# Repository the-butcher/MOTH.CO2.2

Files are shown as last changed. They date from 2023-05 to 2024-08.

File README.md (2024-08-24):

# moth.CO2.2

This projects provides instructions for building a CO₂ sensor from off the shelve electronic parts combined with 3D printed housing parts.

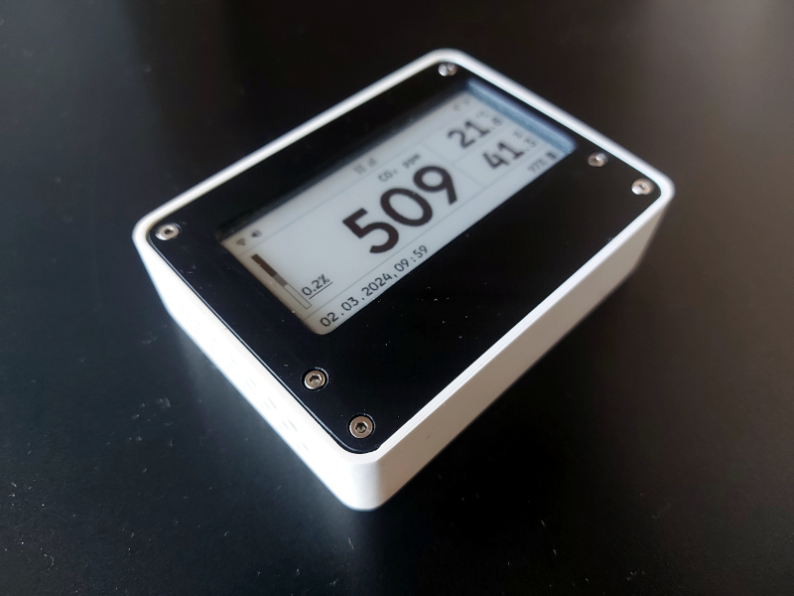
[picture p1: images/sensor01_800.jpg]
CO₂-Sensor fully assembled


- measures
  - CO₂
  - temperature
  - humidity
  - pressure
  - altitude
  - battery

- can last ~6 weeks on a single battery charge, when operated at low power settings, this is the longest battery life of a SCD41 based sensor operated at regular interval as far as i know

- uses the [Sensirion SCD-41](https://www.adafruit.com/product/5190) Sensor, a small and high performance photoacoustic NDIR CO₂ sensor

- offers various ways to access the data measured
  - on the device display in table or chart mode
  - through an integrated [wifi-rest-api](/moth_client/README.md#wifi-rest-api)
  - over the standardized [MQTT protocol](/moth_core/README.md#mqttjson)

- is configurable in many ways
  - thresholds for CO₂, temperature and humidity
  - temperature display in °C or °F
  - sensor timezone
  - temperature offset
  - CO₂ calibration
  - WiFi, [MQTT](https://de.wikipedia.org/wiki/MQTT)

- stores unlimited history of data due to integrated SD-card

- hosts a web-UI on it's internal web-server, usable from mobile and desktop devices

- optionally provides
  - dark/inverted mode
  - acoustic alert

<!-- ![chart mode](/images/sensor03_800.jpg?raw=true)

![WiFi connection](/images/sensor04_800.jpg?raw=true) -->

---

## The project is structured as follows:

### [Core (moth_core)](moth_core/README.md)

This project is built with [PlatformIO](https://platformio.org/). Please refer to the instructions provided on the PlatformIO website. PlatformIO makes development with the ESP32 microcontroller easier and faster compared to the Arduino IDE. If you have not switched yet i advise you to do so, it will save you time after a very short period of time.
The PlatformIO project, and configuration files can be found here.

### [Building instructions (moth_parts)](moth_parts/README.md)

Building instructions, drawings and printable files for the device.

### [Client (moth_client)](moth_client/README.md)

A react UI for data retrieval and administration of the device.

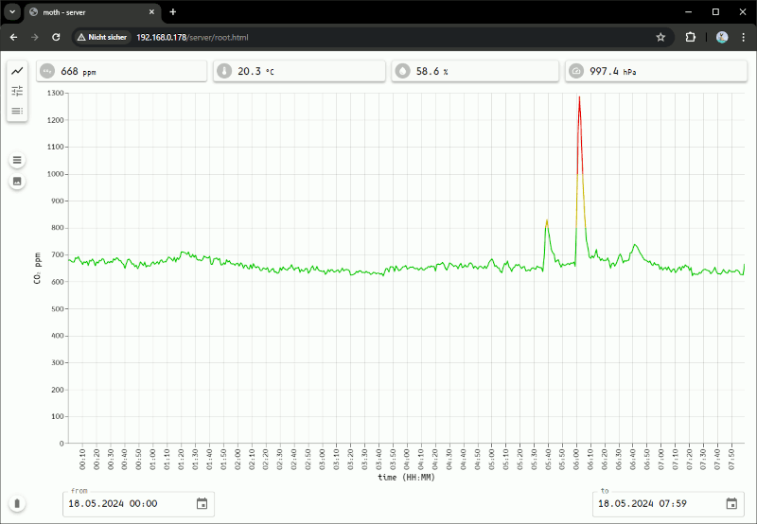
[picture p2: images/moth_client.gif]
web-app client


---

## Device functionality:

### Device usage

- #### Buttons

- #### Table mode

- #### Chart Mode

- #### CO₂ sound alert

- #### Wifi

- #### Dark mode

- #### Altimeter

### Data access

- #### On display

The device display supports multiple display modes, "table", "chart" and "calibration".

  - In table mode the latest CO₂, temperature and  humidity values are shown numerically.
  - In chart mode one of CO₂, temperature, humidity or pressure are shown in a simple chart. The chart can show 1h, 3h, 6h, 12h or 24h data ranges.
  - In calibration mode, the most recent history of values is shown together with simple statistics. The device can then be calibrated either to a configurable value via button press, or through the wifi-rest-api and value that can be specified by the user.

- #### Over the wifi-rest-api

  The device provides various possibilities to access current and historic data over the wifi-rest-api.

- #### MQTT

  It is possible to configure a mqtt connection and upload the mqtt brokers certificate if needed. The device will make connections in configurable intervals und publish it's measurements.
  The sensor can easily be integrated into HomeAssistant.

### Calibration

- #### On display (no wifi required)

The device display can be switched to calibration display mode, then put outside into fresh air. After 10 minutes the recent measurement history standard deviation can be checked and, if within plausible tolerance, the device can be calibrated to a reference value previously configured. See [moth_core/disp.json](/moth_core/README.md#dispjson) and [moth_client/client_config](/moth_client/README.md#client-config) for more details.

- #### Over the wifi-rest-api

The rest-api of the device provides the "co2cal" endpoint. Here it is possible to calibrate the device to any value above 400pmm. This enables calibration to value other than outside air, if known from i.e. other devices (see: [moth_client/wifi-rest-api](/moth_client/README.md#wifi-rest-api)) for more detail.

---

## License

Please be aware that all software in this project is licensed under the [MIT license](license.txt), while the drawings and 3d-printed parts are licensed under the [Attribution-NonCommercial-ShareAlike 4.0 International (CC BY-NC-SA 4.0)](https://creativecommons.org/licenses/by-nc-sa/4.0/) license.

https://github.com/the-butcher/MOTH.CO2.2/assets/84620977/23303f60-04a6-4f3b-a14d-cb0d6dc5e2be

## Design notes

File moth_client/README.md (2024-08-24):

## CLient

---

The client subproject is react-web-application, storable on the device's SD-card and consumable with any browser directly from the device.

The Client UI is split into 3 main pages:

---

- #### client-chart

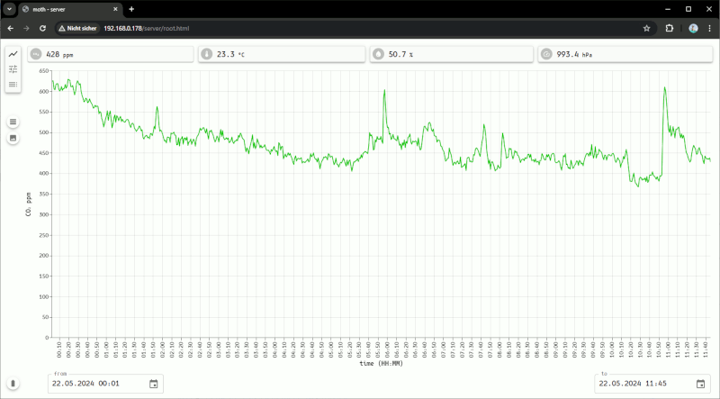
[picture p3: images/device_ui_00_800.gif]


It is possible to show recent and historic data:

- CO₂ (ppm)
- temperature (°C)
- humidity (%RH)
- barometric pressure (hPa)
- battery (%)

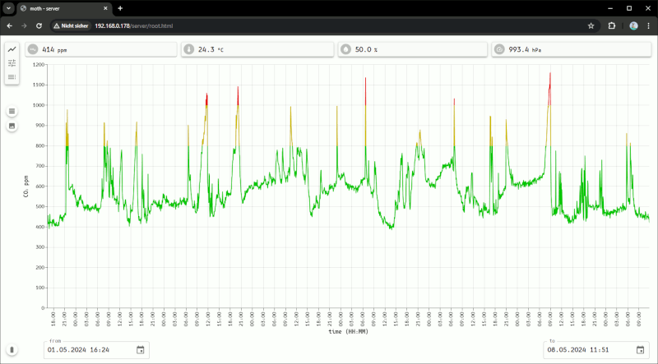
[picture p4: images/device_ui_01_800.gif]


Date/Time Pickers can be used to specify the range of data to be shown in the chart. Since the SD-card is large enough to store the entire lifetime of the sensor, so any date range from the life time of the sensor can be picked.

The displayed range of data can be exported to:

  - CSV
  - PNG

---

- #### client-config

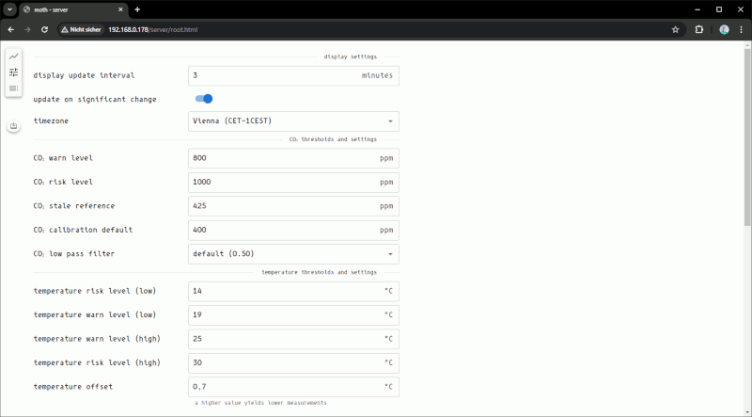
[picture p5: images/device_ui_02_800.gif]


This page offers a convenient way to configure the device through a reactive UI.

- #### client-api

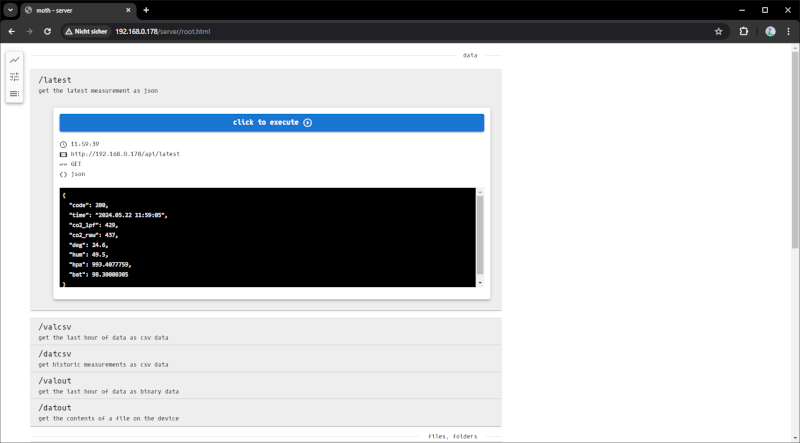
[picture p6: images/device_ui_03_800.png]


This is a helper page to descibe the device's api. This page can either be used as-is, or it can serve as the basis to understand the device api.

---

#### wifi-rest-api

A short list of the device's api:

|url|method|type|description|parameters|
|---|---|---|---|---|
|/api/latest|GET|json|get the latest measurement as JSON|none|
|/api/valcsv|GET|csv|get the last hour of measurements as CSV|none|
|/api/datcsv|GET|csv|get the contents of a data file as CSV|"file"<br>i.e. 2024/05/20230526.dat|
|/api/valcsv|GET|binary|get the last hour of measurements as binary data|none|
|/api/datout|GET|binary|get the contents of a file as binary data|"file"<br>i.e. 2024/05/20230526.dat|
|/api/dirout|GET|json|list the contents of a folder|"folder"<br>i.e. "2024", "2024/05/", "config"|
|/api/upload|POST|json|upload files to the device|"file"<br>i.e. "server/root.html"<br>"content"<br>multipart file content|
|/api/datdel|GET|json|delete files from the device|"file"<br>i.e. 2024/05/20240526.dat|
|/api/dirdel|GET|json|delete folders from the device|"folder"<br>i.e. "2024", "2024/05/"|
|/api/dspset|GET|json|change device display|"p"<br>0: display mode -> v:[0:2]<br>1: display theme -> v:[0:1]<br>2: table value-> v:[0:2]<br>3: chart value-> v:[0:5]|
|/api/status|GET|json|get details about device status|none|
|/api/netout|GET|json|get a list of networks visible to the device|none|
|/api/netoff|GET|json|disconnect the device|none|
|/api/co2cal|GET|json|calibrate the CO₂ sensor to a given reference value|"ref"<br>i.e. 420|
|/api/co2rst|GET|json|reset the CO₂ sensor to factory||
|/api/esprst|GET|json|reset the device||
|/api/update|POST|json|update device firmware|"content"<br>multipart file containing the new binary|

---

There are multiple ways connectivity to the device can be established:

- When no wifi-connection has been configured yet, the device will start in AP-mode, providing it's own network. You can connect you mobile phone or computer to that network and configure i.e. your home wifi. The AP connections password is "CO2@420PPM".
- When wifi-connections have been configured, the device will pick from the configured networks the one with the highest signal strength.

What has been working for me is configuring my home network and my mobile's wifi-hotspot. That way the sensor will connect to the home network most of the time, but there is a fallback to the hotspot of my phone when i'm away. When in a hotel i add the hotel network, so i can save data on the hotspot.

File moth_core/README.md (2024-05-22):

# Core

This folder contains the Arduino Sketch for the moth.CO2.2 sensor and a set of configuration files in [SD](SD) that need be copied to the SD card of the device.

The moth_core folder of the project is structured as follows:

---

Historic versions of the project (kept for reference):

- #### [moth_core_020](moth_core_020)
- #### [moth_core_021](moth_core_021)

Most recent PlatformIO project:

- #### **[moth_core_022](moth_core_022)**

---

Configuration files that define the behaviour of the device.

## [SD/config](SD/config/)

---

- ### [disp.json](SD/config/disp.json)

Configuration for everything related to displaying values.

documentation (please do not use the documented version on the device, but a clean json without the comments):

```
{
  "min": 3, <<< display update time in minutes
  "ssc": true, <<< allow shorter display update when a significant value change occured
  "alt": 153, <<< base altitude of the device
  "tzn": "CET-1CEST,M3.5.0,M10.5.0/3", <<< timezone
  "co2": {
    "wHi": 800, <<< co2 warn limit
    "rHi": 1000 <<< co2 risk limit
    "ref": 425, <<< co2 reference value for stale calculation
    "cal": 400, <<< co2 reference value for fresh air calibration
    "lpa": 0.5  <<< low pass filter alpha, low value yields stronger filtering
  },
  "deg": {
    "rLo": 14, <<< lower temperature (celsius) risk limit
    "wLo": 19, <<< lower temperature (celsius) warn limit
    "wHi": 25, <<< upper temperature (celsius) warn limit
    "rHi": 30, <<< upper temperature (celsius) risk limit
    "off": 1.5, <<< temperature offset of the scd41 sensor
    "c2f": false <<< temperature display in fahrenheit?
  },
  "hum": {
    "rLo": 25, <<< lower humidity (% RH) risk limit
    "wLo": 30, <<< lower humidity (% RH) warn limit
    "wHi": 60, <<< upper humidity (% RH) warn limit
    "rHi": 65  <<< upper humidity (% RH) risk limit
  },
  "bme": {
    "alt": 153, <<< base altitude of the sensor
    "lpa": 0.25 <<< low pass filter alpha, low value yields stronger filtering
  }
}
```
General timezone documentation can be found at:
[timezones](https://github.com/nayarsystems/posix_tz_db/blob/master/zones.csv)

Measurements are stored with local times.

Timezones that have been tested to work are (but other will work too):

|code|where|
|---|---|
|CET-1CEST,M3.5.0,M10.5.0/3|Vienna|
|GMT0BST,M3.5.0/1,M10.5.0|London|
|AST4ADT,M3.2.0,M11.1.0|Atlantic|
|EST5EDT,M3.2.0,M11.1.0|New York|
|CST6CDT,M3.2.0,M11.1.0|Chicago|
|MST7MDT,M3.2.0,M11.1.0|Denver|
|PST8PDT,M3.2.0,M11.1.0|Los Angeles|

example:

```
{
  "min": 3,
  "ssc": true,
  "tzn": "CET-1CEST,M3.5.0,M10.5.0/3",
  "co2": {
    "wHi": 800,
    "rHi": 1000,
    "ref": 425,
    "cal": 400,
    "lpa": 0.5
  },
  "deg": {
    "rLo": 14,
    "wLo": 19,
    "wHi": 25,
    "rHi": 30,
    "off": 1.5,
    "c2f": false
  },
  "hum": {
    "rLo": 25,
    "wLo": 30,
    "wHi": 60,
    "rHi": 65
  },
  "bme": {
    "alt": 153,
    "lpa": 0.25
  }
}
```

- ### [mqtt.json](SD/config/mqtt.json)

Configuration for [MQTT](https://de.wikipedia.org/wiki/MQTT).

documentation (please do not use the documented version on the device, but a clean json without the comments):

```
{
  "use": true, <<< use mqtt?
  "srv": "192.168.0.123", <<< mqtt broker host (required)
  "prt": 8883, <<< mqtt broker port (required)
  "usr": "hannes", <<< mqtt user (optional)
  "pwd": "n7NZ+SfvP68wzUgh3t4acw==", <<< mqtt password (optional)
  "cli": "moth_2", <<< the mqtt client-id that the device will use
  "min": 5 <<< publish interval in minutes
}
```

example (protected, if a certificate is present at "/config/ca.crt" secure):

```
{
  "use": true,
  "srv": "192.168.0.115",
  "prt": 8883,
  "usr": "hannes",
  "pwd": "fleischer",
  "cli": "moth__66",
  "min": 5
}
```

example (unprotected server, if the server does not require a secure connection, the certificate file "/config/ca.crt" should not exist):

```
{
  "use": true,
  "srv": "192.168.0.115",
  "prt": 1883,
  "cli": "moth__66",
  "min": 5
}
```

example (mqtt inactive):

```
{
  "use": false
}
```

for all above configurations, if there is a certificate present at "/config/ca.crt", a secure wifi-connection will be created using that certificate.

- ### [wifi.json](SD/config/wifi.json)

Configuration for the WiFi connection of the decive.

documentation (please do not use the documented version on the device, but a clean json without the comments):

```
{
  "min": 5, <<< wifi timeout in minutes, when not connected to power, wifi will auto turn off after that time
  "ntw": [ <<< an array of network connections
    {
      "key": "your-wifi-ssid", <<< the ssid of your network
      "pwd": "your-wifi-password" <<< the password of your network
    }
  ]
}
```

example:

```
{
  "min": 5,
  "ntw": [
    {
      "key": "your-wifi-ssid",
      "pwd": "your-wifi-password"
    }
  ]
}
```

example (unprotected network):

```
{
  "min": 5,
  "ntw": [
    {
      "key": "your-wifi-ssid",
      "pwd": ""
    }
  ]
}
```

## [SD/server](SD/server/)

The device provides webserver accessible through WiFi. The files in this folder provide a web-application that can be used to administer the device

The files for the webserver are built from the [moth_client_p22](../moth_client_p22/) subproject.

---

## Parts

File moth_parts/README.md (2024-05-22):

# <a name="moth_parts">Parts and Assembly</a>
Building the sensor is split into two main parts. Electric assembly and housing.

---
### [Electric parts](electricparts.md)

List of parts that need to be bought.

---
### [Electric Assembly](electricassembly.md)

Assembly instructions for the electric parts. Simple soldering required.

---
### [Printed parts](printedparts.md)

List of printable parts and some postprocessing hints.

---
### [Device Assembly](deviceassembly.md)

Assembly of the device from electric and printed parts.

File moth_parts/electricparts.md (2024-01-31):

# Electric parts

Parts used in the prototype build:

- <a href="#microcontroller">Adafruit ESP32-S2 Feather with BME280</a>
- <a href="#co2sensor">Adafruit SCD-41 - True CO2 Temperature and Humidity Sensor - STEMMA QT / Qwiic</a>
- <a href="#rtc">Adafruit PCF8523 Real Time Clock Breakout Board - STEMMA QT / Qwiic</a>
- <a href="#cable">STEMMA QT / Qwiic JST SH 4-Pin Cable - 50mm Long x 2</a>
- <a href="#display">Adafruit 2.9" Grayscale eInk / ePaper Display FeatherWing - 4 Level Grayscale</a>
- <a href="#battery">3,7 V 3000mAh 18650 Lithium Li-Ion Battery Pack</a>
- <a href="#buzzer">Buzzer</a>
- <a href="#screws">M2 hardware</a>
- <a href="#inserts">threaded inserts M2 x 4mm</a>
- <a href="#acrylic">acrylic glas 1mm, ~ 78mm x ~36mm</a>

The list contains references to where i got my parts from, if you get alterntive parts please consider any differences that may make for the 3D-printed parts. For example, if you get different threaded nuts, you may have to adapt the openings provided to those inserts.

---

<a href="https://www.adafruit.com/product/5303" name="microcontroller">Adafruit ESP32-S2 Feather with BME280</a> The microcontroller. Not an S3, but it has an BME-280 Sensor onboard, thus saving an extra part to be fit into the housing. The processors power is far beyond necessary and the pressure sensor delivers extra precision to the CO₂ sensor.

Adafruit ESP32-S2 Feather with BME280

---

<a href="https://www.adafruit.com/product/5190" name="co2sensor">Adafruit SCD-41 - True CO2 Temperature and Humidity Sensor - STEMMA QT / Qwiic</a> The actual CO₂ sensor. Easy to connect due STEMMA QT connection with the microcontroller.

Adafruit SCD-41 - True CO2 Temperature and Humidity Sensor - STEMMA QT / Qwiic

---

<a href="https://www.adafruit.com/product/5189" name="rtc">Adafruit PCF8523 Real Time Clock Breakout Board - STEMMA QT / Qwiic</a> Battery-backed real time clock (RTC)

Adafruit PCF8523 Real Time Clock Breakout Board - STEMMA QT / Qwiic

---

<a href="https://www.adafruit.com/product/4399" name="cable">STEMMA QT / Qwiic JST SH 4-Pin Cable - 50mm Long</a> Cables connecting microcontroller, RTC and CO₂ sensor. 2 cables are needed.

STEMMA QT / Qwiic JST SH 4-Pin Cable - 50mm Long

---

<a href="https://www.adafruit.com/product/4777" name="display">Adafruit 2.9" Grayscale eInk / ePaper Display FeatherWing - 4 Level Grayscale</a> Grayscale e-ink display

Adafruit 2.9 Grayscale eInk / ePaper Display FeatherWing - 4 Level Grayscale

---

<a href="https://batteryzone.de/products/3-7-v-3000mah-18650-lithium-li-ion-batterien-pack-wiederaufladbare-mit-xh-2-54mm-2pin-stecker-fur-rc-boot-diy-power-bank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" name="battery">3,7 V 3000mAh 18650 Lithium Li-Ion Battery Pack</a>  18650 Battery Pack with PH2.0 plug.

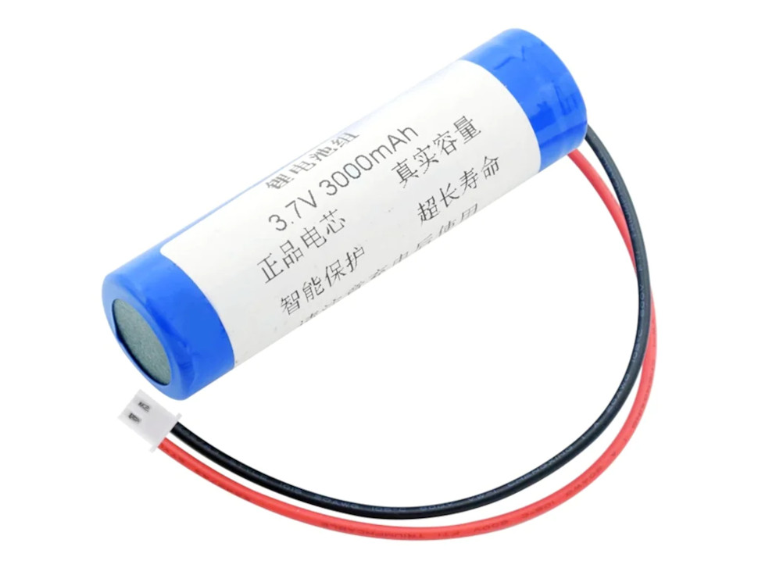
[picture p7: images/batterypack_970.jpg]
3,7 V 3000mAh 18650 Lithium Li-Ion Battery Pack


---

<a href="https://www.mouser.at/ProductDetail/TDK/PS1240P02BT?qs=d7g9p1yFhWaZXSY9MjKMkw%3D%3D" name="buzzer">Buzzer</a>

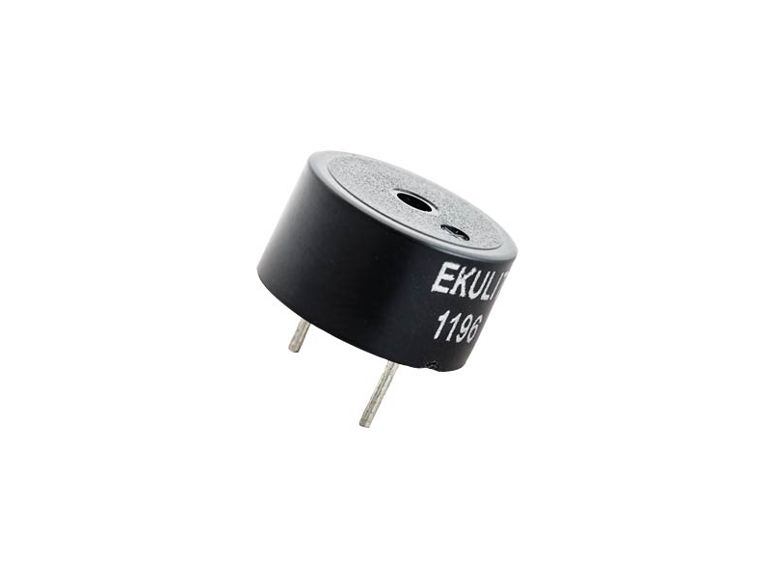
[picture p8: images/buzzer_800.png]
Buzzer


---

- <a name="screws">M2 hardware:</a>

  - 8 screws M2 x 5mm
  - 4 screws M2 x 8mm
  - 8 nuts M2

---

- 4 <a href="https://www.reichelt.at/at/de/3d-druck-gewindeeinsaetze-m2x4-70-stueck-rx-m2x4-p332211.html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" name="inserts">threaded inserts M2 x 4mm</a>

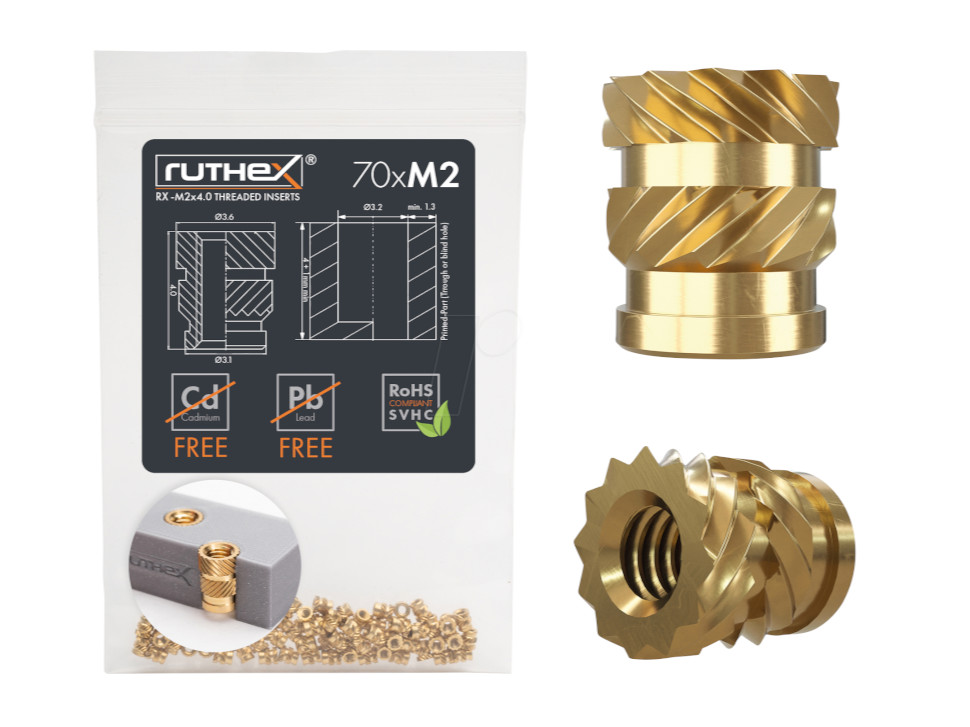
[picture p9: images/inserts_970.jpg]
threaded inserts M2 x 4mm


---

- <a name="acrylic">acrylic glas 1mm, ~ 78mm x ~36mm</a>

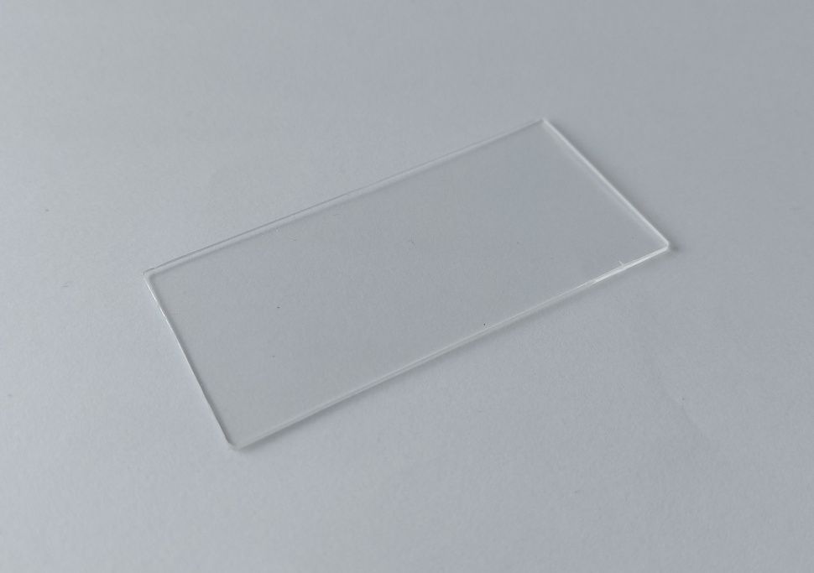
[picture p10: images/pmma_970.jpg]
acrylic glas 1mm


---

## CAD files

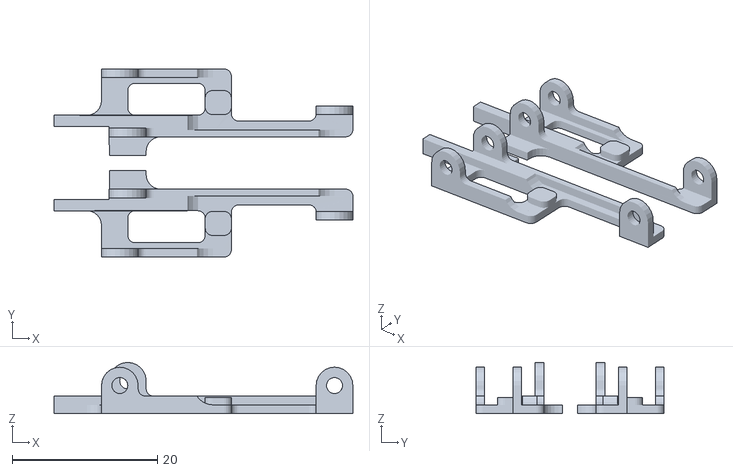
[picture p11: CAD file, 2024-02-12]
moth_parts/supports2.stl
41.1 x 25.9 x 7.03

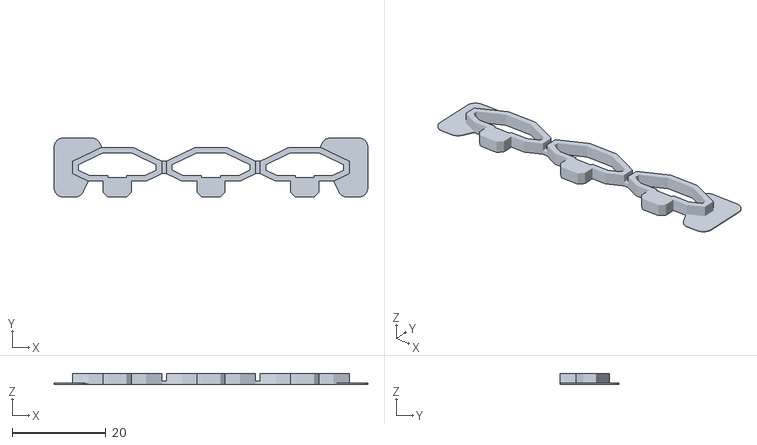
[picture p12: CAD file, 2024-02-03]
moth_parts/buttons_tpu.stl
67.0 x 12.6 x 2.42

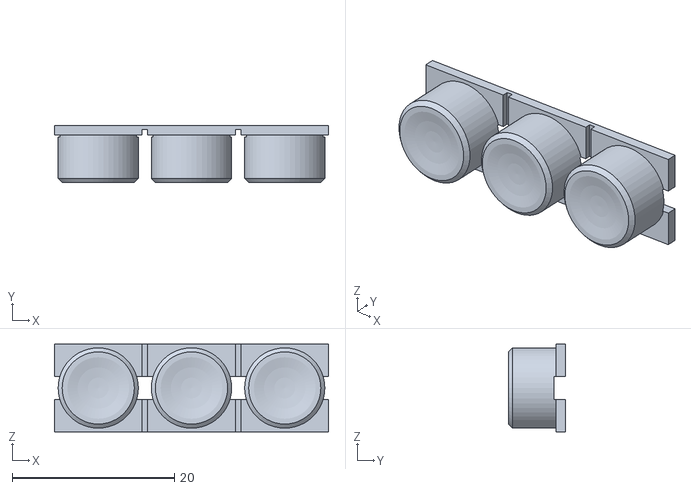
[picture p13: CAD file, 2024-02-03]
moth_parts/buttons.stl
33.8 x 7.05 x 10.8

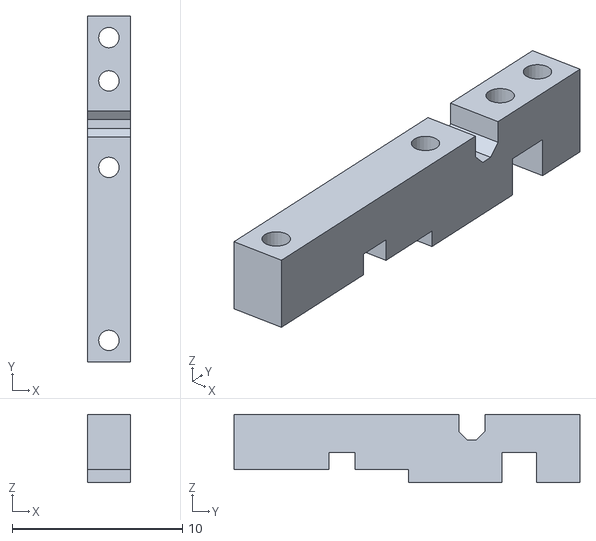
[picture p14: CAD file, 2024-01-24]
moth_parts/boostbuzz.stl
2.52 x 20.3 x 4.00

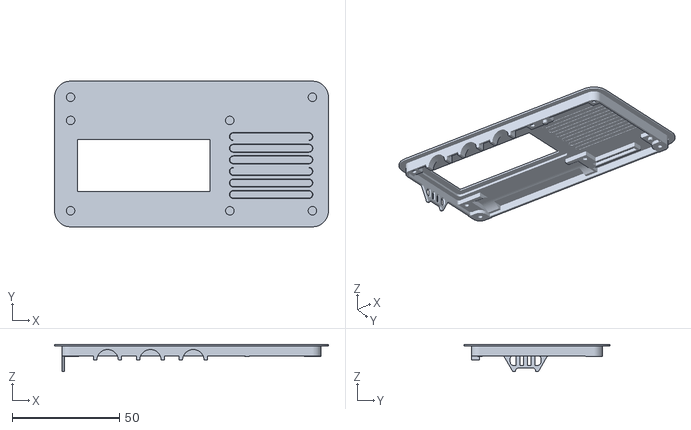
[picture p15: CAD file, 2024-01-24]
moth_parts/housing_upper_pms.stl
127.9 x 68.0 x 12.8

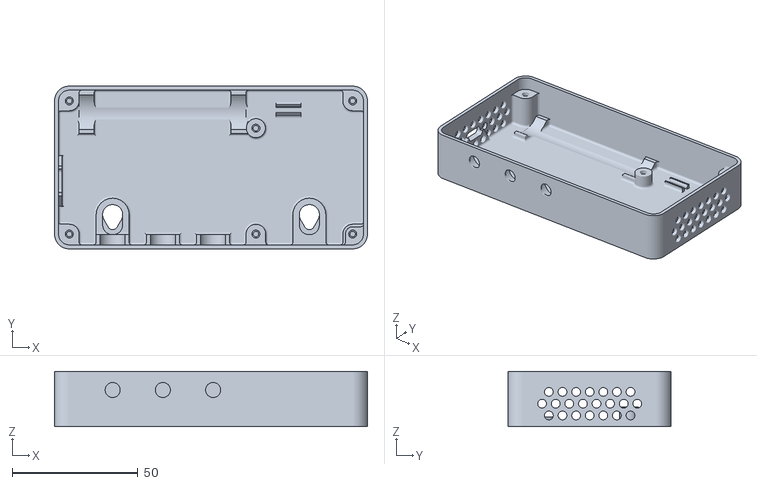
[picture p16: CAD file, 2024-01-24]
moth_parts/housing_lower_pms.stl
124.7 x 64.8 x 22.0

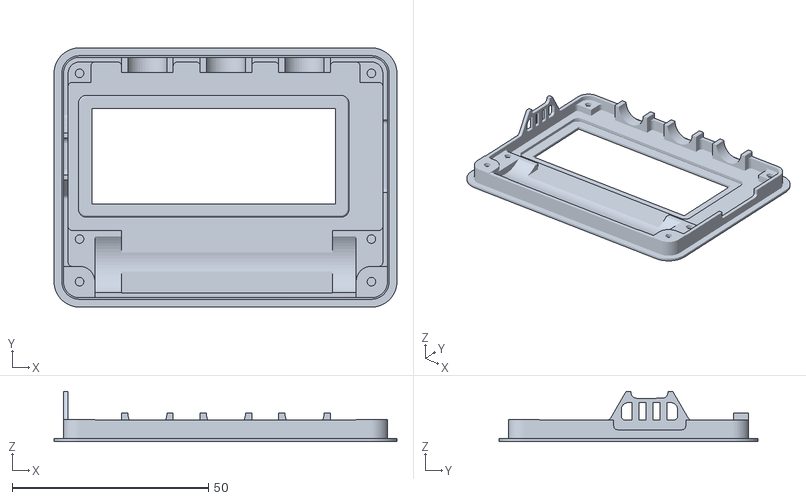
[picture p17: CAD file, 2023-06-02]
moth_parts/housing_upper_b.stl
87.3 x 66.0 x 12.8

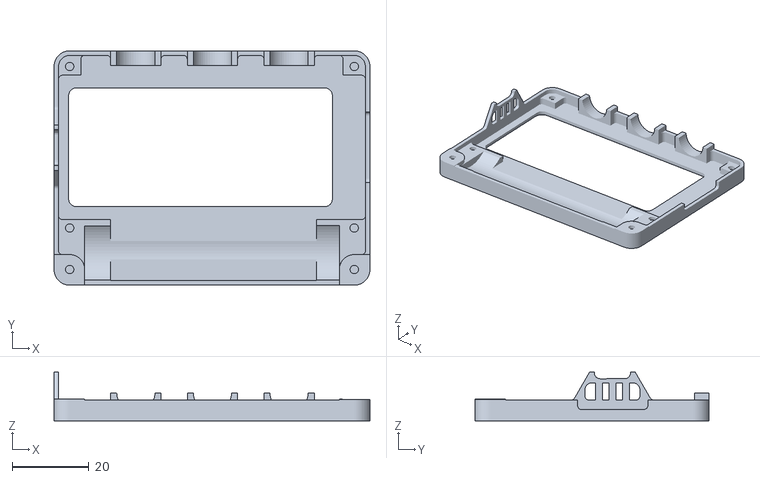
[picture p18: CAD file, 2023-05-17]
moth_parts/housing_upper.stl
82.5 x 61.2 x 12.8

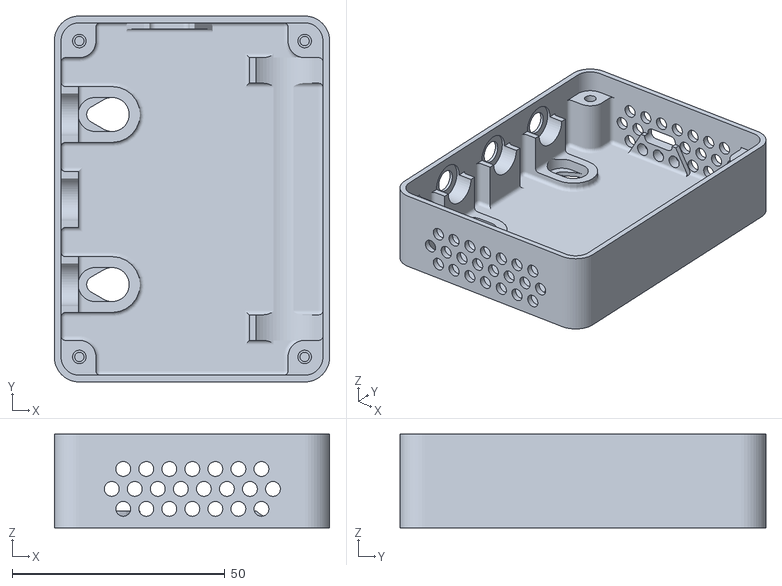
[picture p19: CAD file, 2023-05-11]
moth_parts/housing_lower_s.stl
64.8 x 86.1 x 22.0

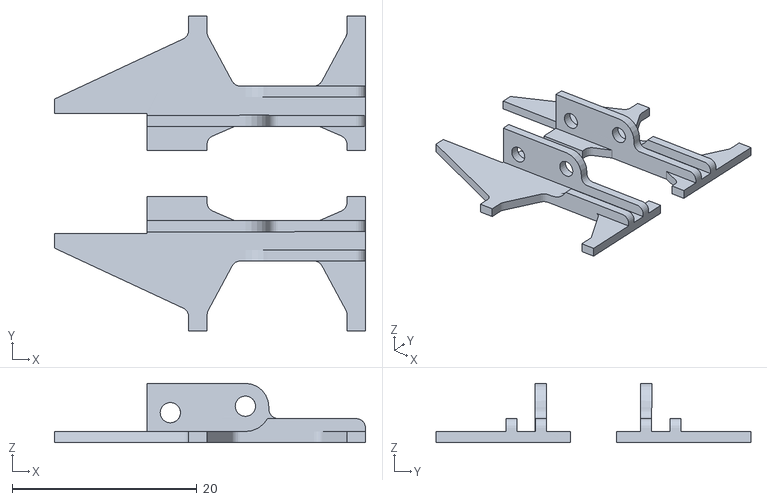
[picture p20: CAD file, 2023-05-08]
moth_parts/supports.stl
33.7 x 34.1 x 6.42

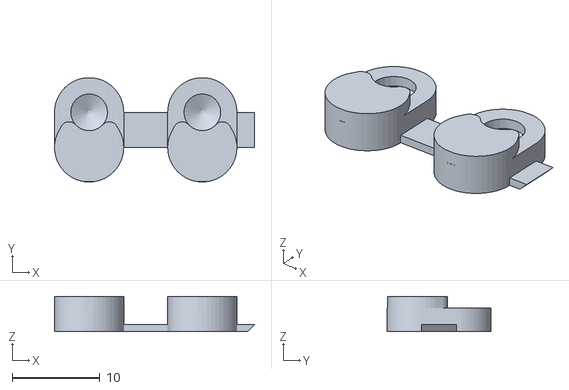
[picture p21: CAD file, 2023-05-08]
moth_parts/mountplugs.stl
22.8 x 11.9 x 4.02

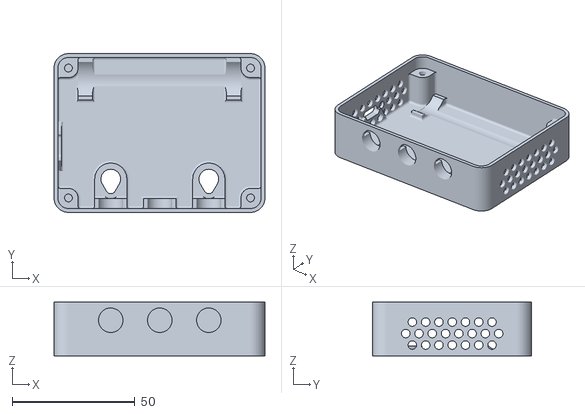
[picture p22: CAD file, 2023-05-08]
moth_parts/housing_lower.stl
86.1 x 64.8 x 22.0

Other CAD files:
moth_parts/boostbuzz.skp
moth_parts/buttons.skp
moth_parts/buttons_tpu.skp
moth_parts/housing_lower.skp
moth_parts/housing_lower_pms.skp
moth_parts/housing_upper.skp
moth_parts/housing_upper_pms.skp
moth_parts/mountplugs.skp
moth_parts/supports.skp
moth_parts/supports2.skp

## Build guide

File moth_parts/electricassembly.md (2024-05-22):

# Electric Assembly

Lay the display flat on a soft surface (i.e. a piece of soft cloth). On the backside of the display solder a connection from the pad corresponding to the A4 pin to the pad labelled with "busy".

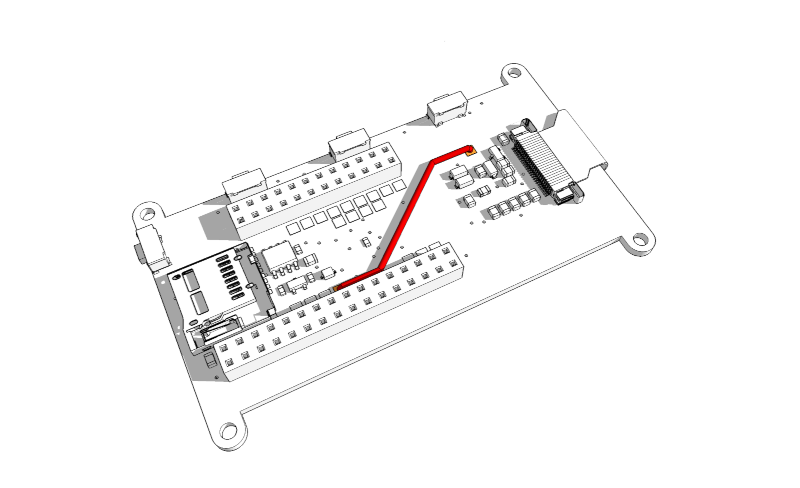
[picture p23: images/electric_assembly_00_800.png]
connect busy


---

Place the microcontroller directly over the the display. Stick short pins (should portrude ~1mm out when fully inserted) through each microcontroller pinhole into the respective display pinholes. Do NOT use a pin header strip, the microcontroller must sit directly on the display.

- Do NOT add a pin to the RST pinhole. This pin will be bridged to from the A0 pin to allow for display only reset. Adding the possibility to reset the display during runtime will save power between display updates. There is also an issue with gray speckles showing on the grayscale eInk display while powered, being able to hibernate the display and reset it later takes care of this issue.
- Do NOT add a pin to the D13 pinhole. The D13 pin on the Adafruit Feather ESP32-S2 is tied to the D13 pin, but this pin is also being used by the C-Button of the eInk display. Therefore the red led of the ESP will always be on when using INPUT_PULLUP for this pin. This consumes power and shortens battery life. This pin will be bridged to from the D6 pin. That way the C-Button is effecticely rerouted to D6 and the red led will no be on, thus saving power.

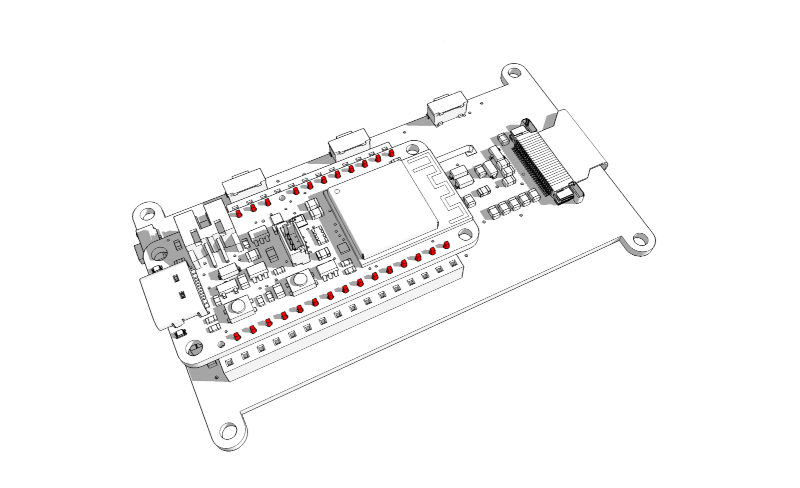
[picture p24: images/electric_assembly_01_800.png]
pins


---

Solder all pins (not RST, not D13) to the microcontroller. After soldering you can separate microcontroller and display. You should now have the microcontroller with short pins soldered to it.

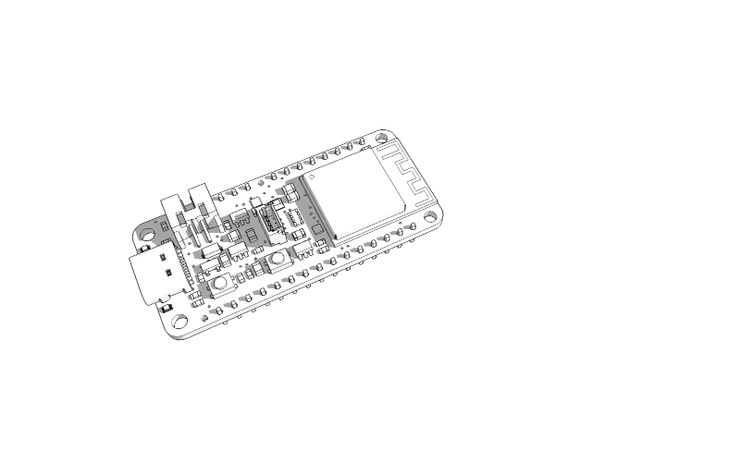
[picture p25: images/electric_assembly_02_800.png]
s2 with pins


---

3d-print [STL "supports2"](supports2.stl), clean printed parts with a file or sandpaper, cleanup holes with a 2mm drill if required. Use 6 M2 x 5mm screws and 6 M2 nuts to connect the feather esp32-s2 microcontroller and the scd-41 sensor. Try not to touch the CO₂ sensors central part to avoid contamination. Connect microcontroller, RTC and scd-41 sensor with the Stemma QT cables (not pictured).

I removed the yellow leds from both RTC and scd-41 with a scalpel. This will significantly prolong battery lifetime, but you must be aware that it will void the warranty for the respective parts.

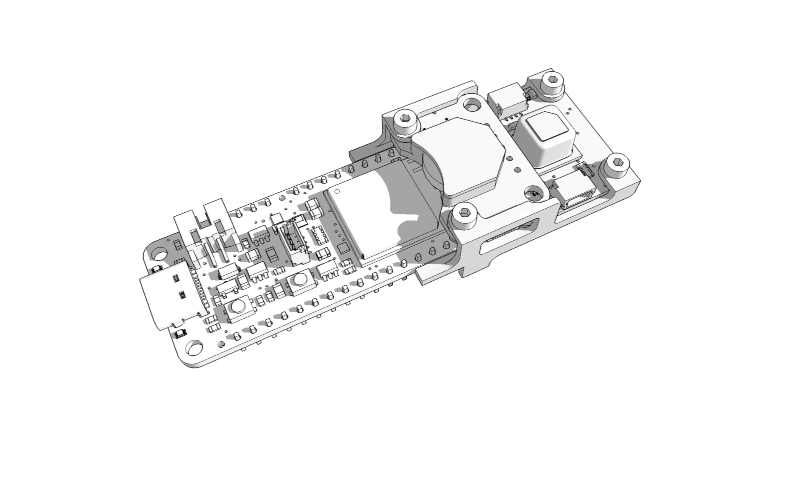
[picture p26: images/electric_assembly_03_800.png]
s2 scd41 and supports


---

Carefully reattach to display to get a unit of display, microcontroller, RTC and CO₂ sensor.

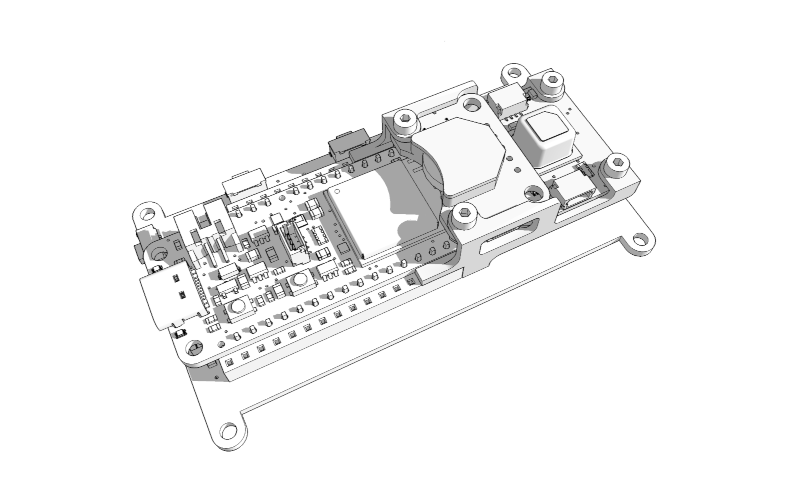
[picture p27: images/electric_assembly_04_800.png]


---

- Connect the pinhole corresponding to the microcontrollers A0 pin to the display RST pinhole. Normally the display would have been hardwirded to be microcontrollers reset button, but we need to be able to reset the display at runtime and this gives the possiblity to do so.
- Connect the pinhole corresponding to the microcontrollers D6 pin to the pinhole corresponding to the microcontrollers A13 pin. This allows for operation of the C-Button on the display without having the microcontrollers red led on.
- Connect the SQW pin of the RTC to the microcontrollers A5 pin. I used thin pliers to bend the connection wire so it would follow the contour of the support parts.

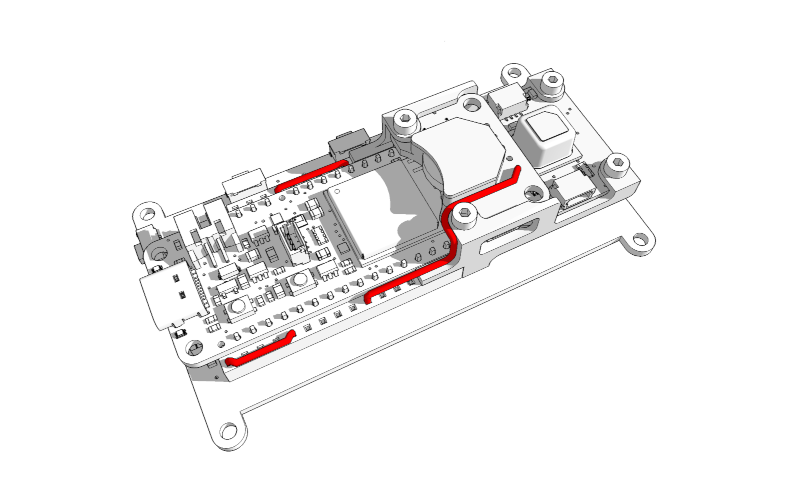
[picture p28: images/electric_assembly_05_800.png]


---

Attach the Buzzer so its pins go into GND and A1.

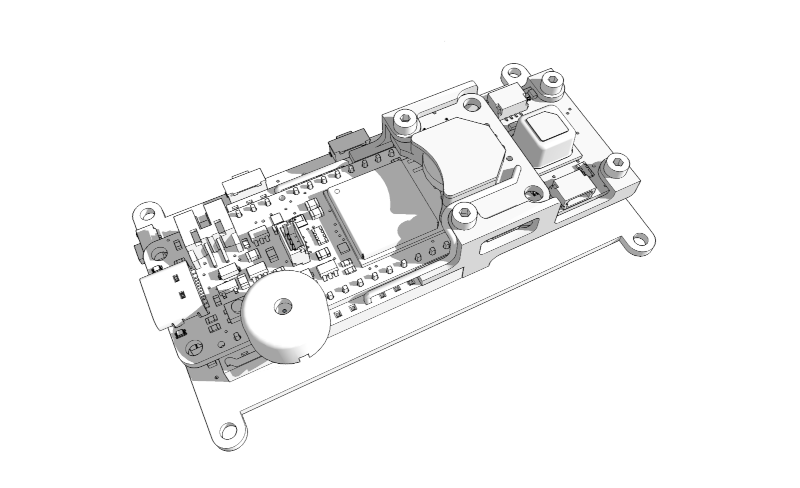
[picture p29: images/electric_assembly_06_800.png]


---

The Electric Assembly is now ready to be configured and to have a sketch uploaded. Please refer to [Core](../moth_core/README.md) for further instructions.

---

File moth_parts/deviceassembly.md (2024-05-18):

# Device Assembly

After having built the [Electric Assembly](electricassembly.md) and having printed and finished all [Printed parts](printedparts.md) all parts can be assembled to the full device.

---

User your soldering iron to press the threaded inserts into the lower housing, then insert the mountplugs into the lower housing if needed.

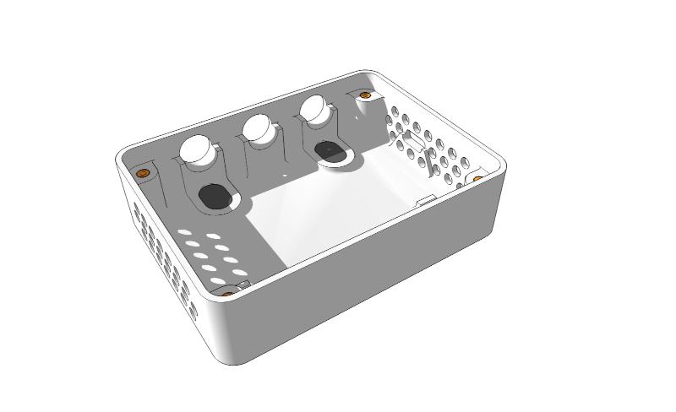
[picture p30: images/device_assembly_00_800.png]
lower housing


---

Cut a rectangle of acrylic glass to fit the upper housing.

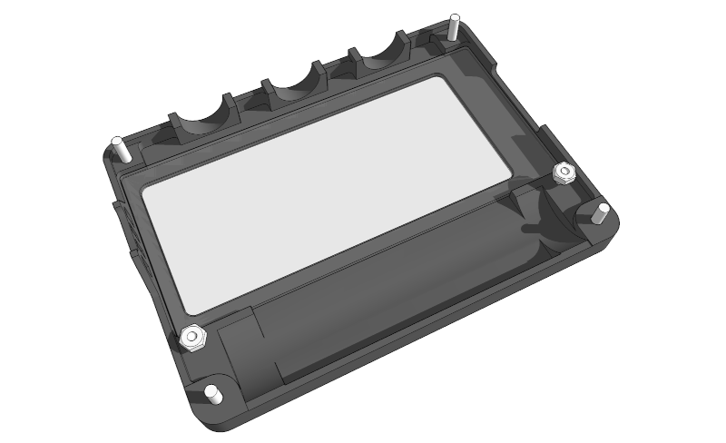
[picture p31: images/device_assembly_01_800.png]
acrylic glas 1mm


---

Place the [Electric Assembly](electricassembly.md) on top of the acrylic glass onto the upper housing and use 2 M2 x 5 screws and 2 M2 nuts to attach.

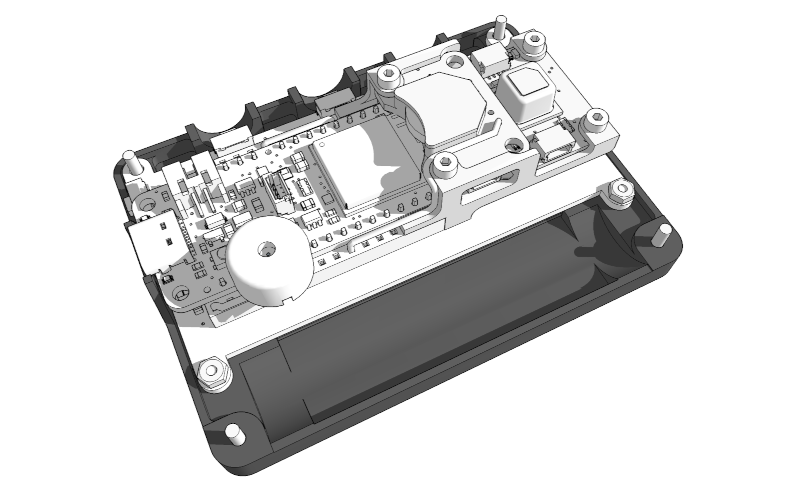
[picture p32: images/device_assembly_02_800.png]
electric assembly mount


---

Add the battery and find a place to lead the cable to the battery plug on the microcontroller. Double- and triplecheck polarity of the battery before plugging it into the microcontroller. I added 2 little drops of glue under the battery to ease handling afterwards.
I had to file a little edge off the buzzer to make battery and buzzer fit nicely.

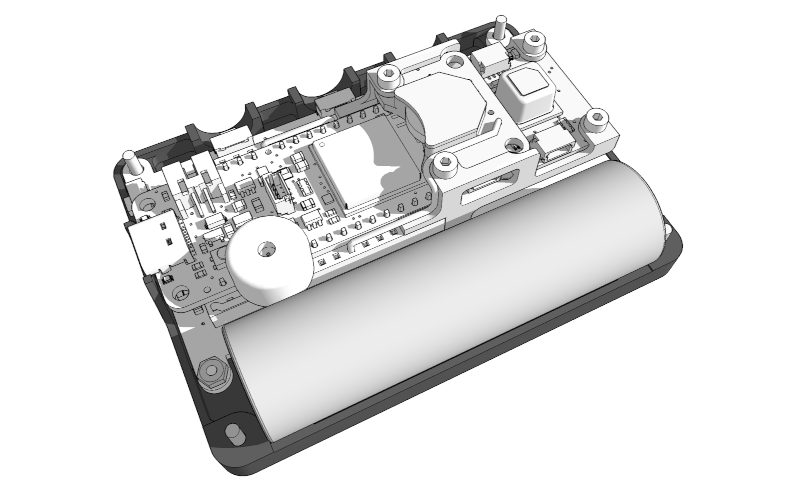
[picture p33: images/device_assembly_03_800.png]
battery


---

Seat the assembled buttons into the assembly and be sure each button can operate freely.

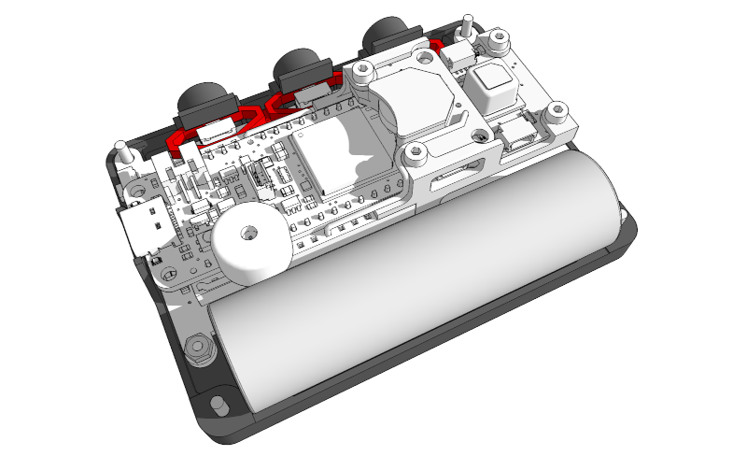
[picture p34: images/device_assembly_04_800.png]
buttons in lower housing


---

Place the lower housing upright so it can accept the rest of the assembly.

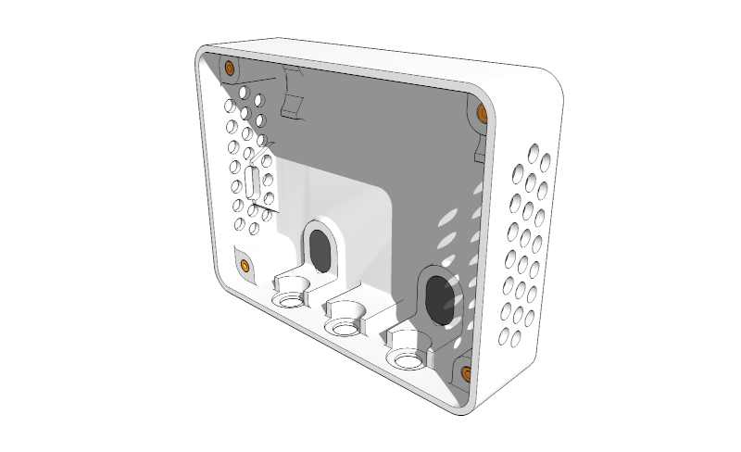
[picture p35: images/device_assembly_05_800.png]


---

Insert the assembly, buttons first, be sure all cables go in smoothly and dont block one the threads that connect lower and upper housing.
Once inserted add 4 M2 x 8mm screws for final attachment.

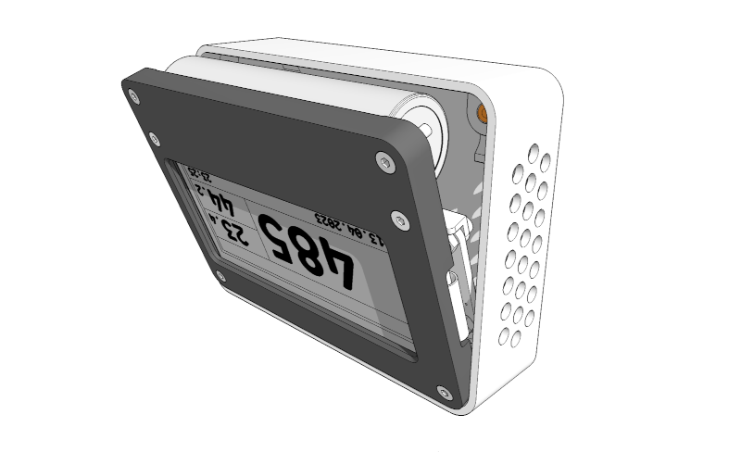
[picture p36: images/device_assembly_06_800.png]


---

Fully assembled.

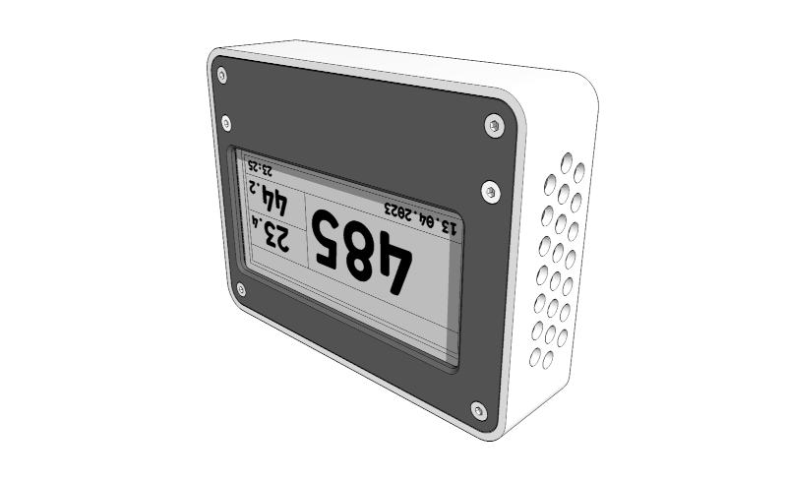
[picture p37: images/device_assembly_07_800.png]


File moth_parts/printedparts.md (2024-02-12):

# PRINTED parts

### [Lower Housing](housing_lower.stl)

This is the part taking the longest to print and also the one requiring most finishing.

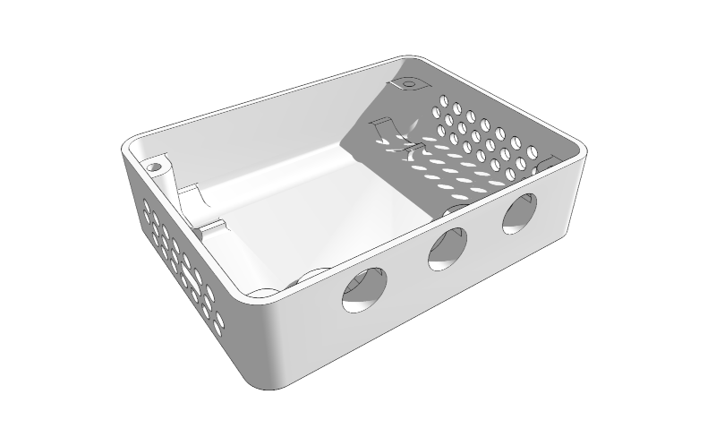
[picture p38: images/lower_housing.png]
lower housing


You can leave this part as it is and it should still work, but the device will look much better if you sand the layered surfaces to a smooth finish. I used 180 grain sandpaper on the surfaces marked red, then worked my way up to 320 grain, then 400 and 600.

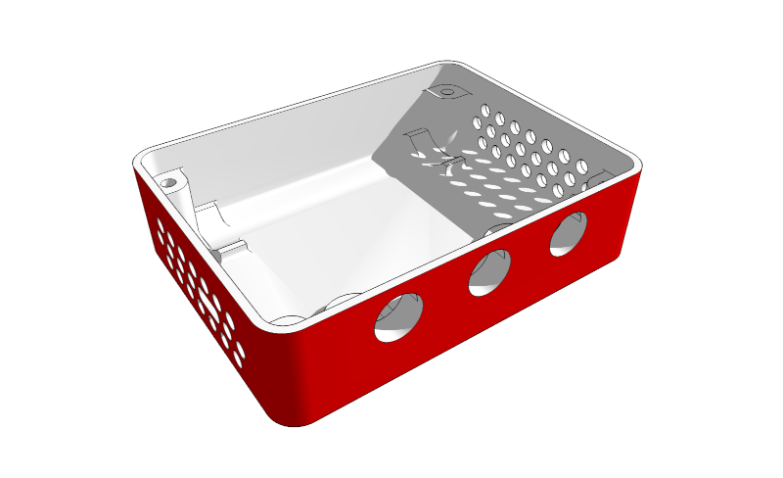
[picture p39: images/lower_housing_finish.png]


Next, i cleaned up the button openings for smooth button operation. Last step was opening all venting holes with a 4mm drill, this gives crisp edged on the surface and removes any artifact from printing overhang.

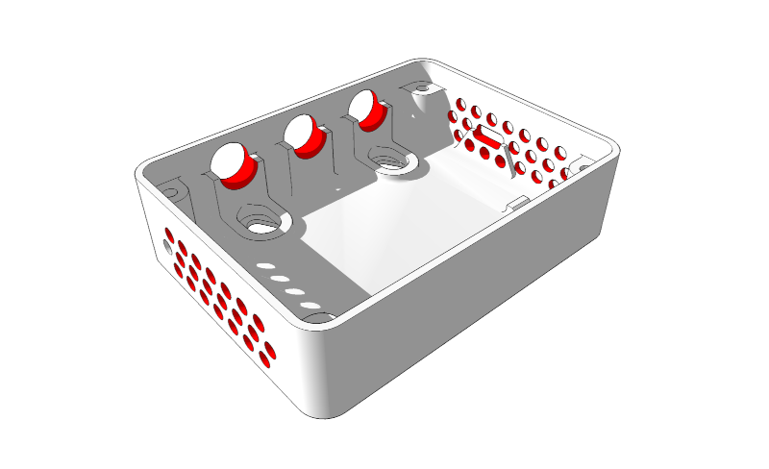
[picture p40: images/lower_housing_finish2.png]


---

### [Upper Housing](housing_upper.stl)

The upper housing takes less time to print and does not require any substantial finishing.

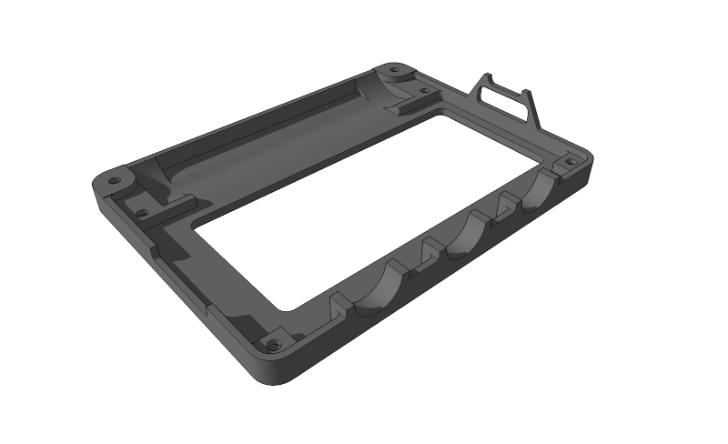
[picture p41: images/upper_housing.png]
upper housing


Again, you should be able to use the part as it is, but it will look better when you file/sand the display opening. You have to open the screwholes with a 2mm drill.

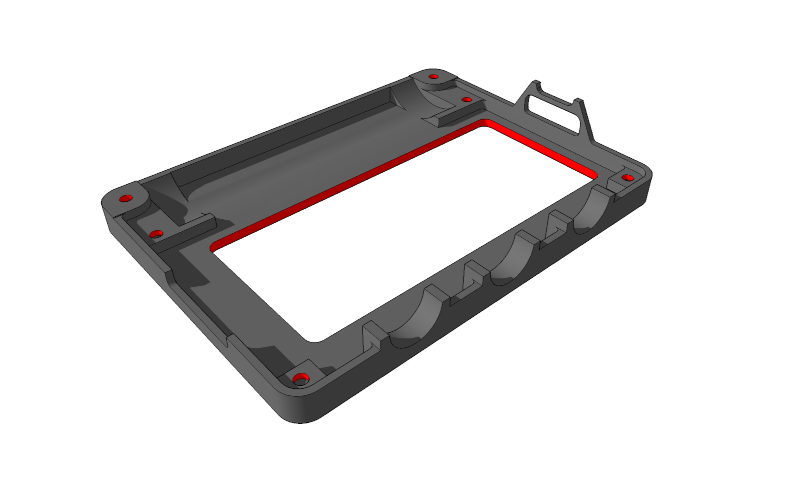
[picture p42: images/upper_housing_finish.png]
upper housing


#### [Upper Housing with raft](housing_upper_b.stl)

For unknown reasons, i had problems with warping on the upper housing part. To fix these issues, there is another version with thick rafts around the part borders.
---

### [Supports](supports2.stl)

The supports serve to connect microcontroller, RTC and the CO₂ sensor and also act as flexible support for the CO₂ sensor to reduce mechanical load should the device be dropped.

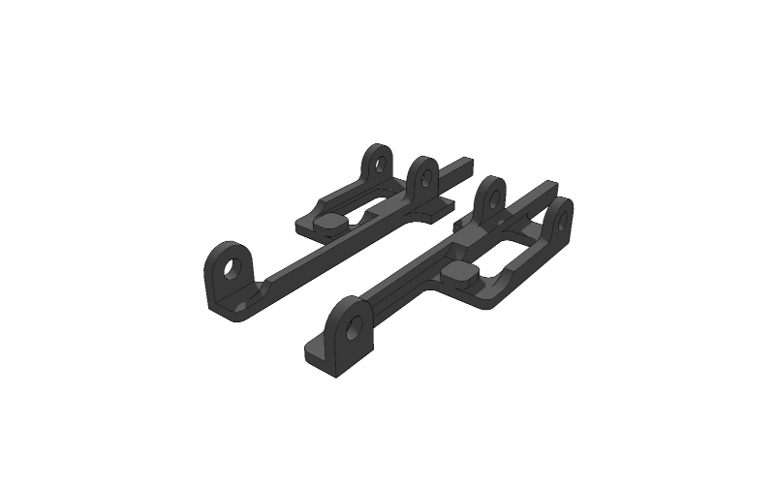
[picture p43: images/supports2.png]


---

### [Buttons](buttons.stl) and [Buttons springs](buttons_tpu.stl)

The buttons can later be used to toggle wifi, display and acoustic feedback.

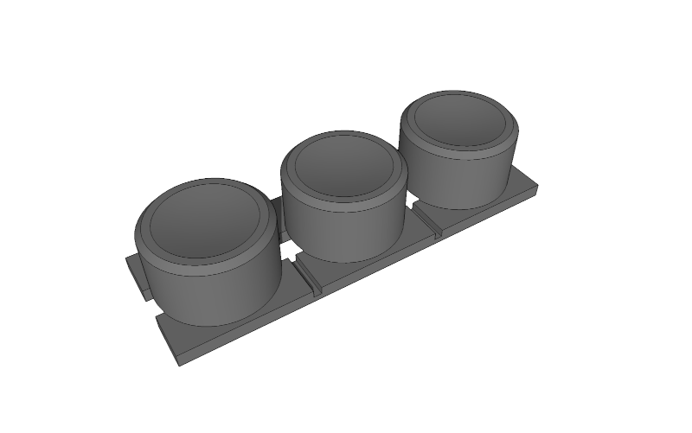
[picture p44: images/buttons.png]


Separate the buttons and clean with sandpaper.

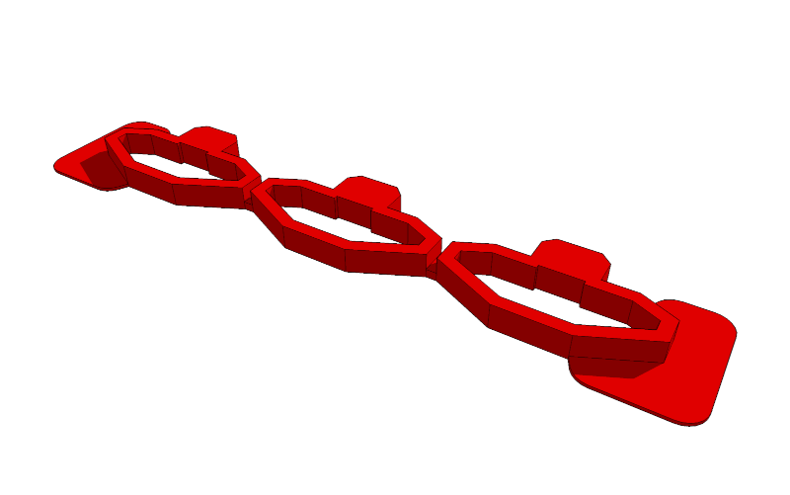
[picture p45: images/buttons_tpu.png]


This part needs to be printed with TPU. It adds flexible action to the buttons and also maintains some pressure on the button so there will be no loose sound when moving the device.
Once printed, remove the rafts with a sharp knive and clean up very precice for later fit.

---

### [Mountplugs](mountplugs.stl)

These little parts go into the wall mount openings of the lower housing. When inserted as printed, the device can not be wall mounted. When drilling through the plugs with a 4mm drill, but leavong the plug in the lower housing, the device can be mounted fixed which provides some degree of theft protection. When omitted altogether the device can be taken on or off the wall.

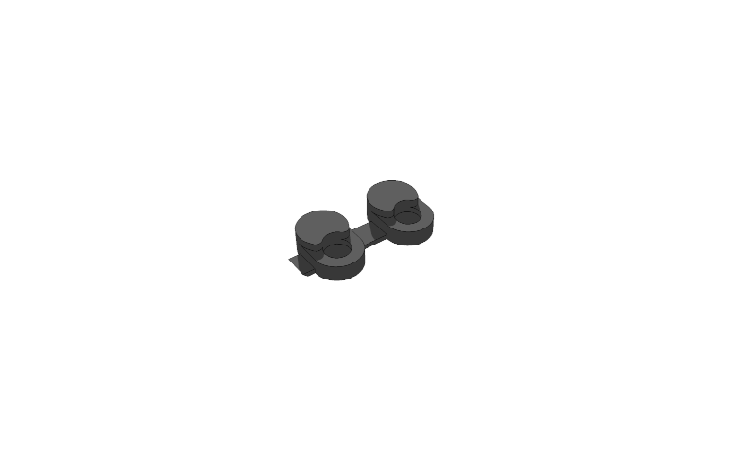
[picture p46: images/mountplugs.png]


---

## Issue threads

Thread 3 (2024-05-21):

do not allow device calibration when the variance of the previous measurements is too large

the-butcher, 2024-05-21:
The device allows calibration, even when the previous values are very high or have a high variation.

There should be limits both value-range and variance wise. If these thresholds are exceeded the calibrate button should not show an icon and should not be functional.

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

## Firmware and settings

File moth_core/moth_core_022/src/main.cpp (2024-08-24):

#include <Arduino.h>
#include <Wire.h>
#include <driver/rtc_io.h>
#include <esp_wifi.h>

#include "buttons/ButtonAction.h"
#include "modules/ModuleCard.h"
#include "modules/ModuleDisp.h"
#include "modules/ModuleMqtt.h"
#include "modules/ModuleSignal.h"
#include "modules/ModuleWifi.h"
#include "sensors/SensorBme280.h"
#include "sensors/SensorEnergy.h"
#include "sensors/SensorScd041.h"
#include "sensors/SensorTime.h"
#include "types/Action.h"
#include "types/Config.h"
#include "types/Define.h"
#include "types/Device.h"
#include "types/Values.h"

RTC_DATA_ATTR setup_mode_t setupMode = SETUP_BOOT;
RTC_DATA_ATTR uint32_t secondstimeBoot;

// configuration and display state
RTC_DATA_ATTR config_t config;  // size: ~140

// last hour of measurements and associated indices
RTC_DATA_ATTR values_t values;  // size: ~1220

// device state
RTC_DATA_ATTR device_t device;  // size: ~136

// does not need to be RTC_DATA_ATTR, reset to 0 does not matter
uint16_t actionNum = 0;

// uint16_t sc = sizeof(device);

/**
 * -- MQTT:
 *    -- occasional timeouts in mosquitto log
 * -- WIFI:
 *    -- wifi sometimes turns off for unknown reasons (more likely when multiple requests are pending),
 * -- MISC:
 *    -- be sure data is written exactly every 60 minutes (not 59 or 61)
 *    -- ideally data would also be flushed with the full hour
 *    -- save data on HTTP reset (have shorter no-data periods)
 * -- the settings action should be able to run at intervals shorter than display interval (i.e. mqtt at 1 minute interval)
 */

// schedule setting and display
void scheduleDeviceActionSetting() {
    device.actionIndexMax = DEVICE_ACTION_DEPOWER;  // allow actions display and depower by index
    uint32_t secondstime = SensorTime::getSecondstime();
    uint32_t secondswait = 60 - secondstime % 60;  // CHECK_MEASURE_INTERVAL
    if (device.actionIndexCur == DEVICE_ACTION_POWERUP && secondswait > WAITTIME_DISPLAY_AND_DEPOWER) {
        device.actionIndexCur = DEVICE_ACTION_SETTING;
        device.deviceActions[DEVICE_ACTION_SETTING].secondsNext = SensorTime::getSecondstime();  // assign current time as due time
    }
}

void scheduleDeviceActionPowerup() {
    // TODO :: only if nothing else (calibration, ... ) is pending
    device.actionIndexCur = DEVICE_ACTION_POWERUP;
    device.deviceActions[DEVICE_ACTION_POWERUP].secondsNext = SensorTime::getSecondstime();
}

/**
 * handle a detected button action or a wifi event
 */
void handleActionComplete(std::function<bool(config_t& config)> actionFunction) {
    if (actionFunction != nullptr) {
        bool actionResult = actionFunction(config);  // execute the action (which, by convention, only alters the config to not interfere with program flow)
        if (actionResult) {
            ModuleSignal::beep();           // indicate complete
            scheduleDeviceActionSetting();  // schedule DEVICE_ACTION_SETTING and DEVICE_ACTION_DISPLAY
        }
    }
    actionNum++;  // interrupt delay loop
}

void scheduleDeviceActionDepower() {
    device.actionIndexCur = DEVICE_ACTION_DEPOWER;
    device.deviceActions[DEVICE_ACTION_DEPOWER].secondsNext = SensorTime::getSecondstime();
    actionNum++;  // interrupt delay loop
}

void handleWakeupCause() {
    esp_sleep_wakeup_cause_t wakeupReason = esp_sleep_get_wakeup_cause();
    if (wakeupReason == ESP_SLEEP_WAKEUP_EXT0) {
        scheduleDeviceActionDepower();
    } else if (wakeupReason == ESP_SLEEP_WAKEUP_EXT1) {
        uint64_t wakeupStatus = esp_sleep_get_ext1_wakeup_status();
        gpio_num_t wakeupPin = (gpio_num_t)(log(wakeupStatus) / log(2));
        if (wakeupPin == PIN_RTC_SQW) {  // wakeup from pin other than the rtc pulse, must be a button press
            scheduleDeviceActionPowerup();
        } else {
            ButtonAction::createButtonAction(wakeupPin);
        }
    }
}

void setup() {

    esp_log_level_set("*", ESP_LOG_NONE);

    // turn on I2C power
    rtc_gpio_deinit((gpio_num_t)I2C_POWER);
    pinMode(I2C_POWER, OUTPUT);
    digitalWrite(I2C_POWER, HIGH);

    Wire.begin();

#ifdef USE___SERIAL
    Serial.begin(115200);
    delay(3000);
#endif

    // must have begun to set color
    ModuleSignal::begin();
    ModuleSignal::setPixelColor(COLOR___YELLOW);

    // must have begun before calling setup
    SensorTime::begin();

    // must have begun to be configured
    SensorScd041::begin();
    SensorBme280::begin();
    SensorEnergy::begin();

    if (setupMode == SETUP_BOOT) {

        delay(1000);  // SensorTime appears to take some time to initialize, especially on boot

        config = Config::load();
        values = Values::load();
        device = Device::load();

        SensorTime::configure(config);    // enables the 1 minute timer
        ModuleWifi::configure(config);    // recreate the wifi data file, this will also call the initial ModuleSdCard begin
        ModuleMqtt::configure(config);    // recreate the mqtt data file
        ModuleDisp::configure(config);    // load display config and apply to config, must be configured prior to SensorScd041 to have correct temperature offset
        SensorScd041::configure(config);  // starts periodic measurement

        // have a battery measurement for the entry screen
        SensorEnergy::powerup();
        SensorEnergy::measure();
        SensorEnergy::depower();

        setupMode = SETUP_MAIN;
        secondstimeBoot = SensorTime::getSecondstime();
    }

    // enable global access to values
    Config::begin(&config);
    Values::begin(&values);
    Device::begin(secondstimeBoot);

    // show the correct button hints and have callback in place
    ButtonAction::begin(handleActionComplete);
    ButtonAction::adapt(config);

    // only sets the callback, but does not powerup anything
    ModuleDisp::begin();
    ModuleWifi::begin(handleActionComplete);

    // there can be multiple causes for wakeup, RTC_SQW pin, BUSY pin, Button Pins
    handleWakeupCause();
}

/**
 * check if the device needs to stay awake
 * - while a button is pressed
 * - while actionPin is set (action is still active)
 * - while WiFi is on
 * - for debugging purposes
 */
bool isDelayRequired() {
#ifdef USE____DELAY
    return true;
#endif
    return ButtonAction::getActionPin() > 0 || ButtonAction::getPressedPin() > 0 || ModuleWifi::isPowered();
}

/**
 * puts the device to deep-sleep for a given amount of seconds
 * when in deep-sleep, the device can wake up from:
 * - a button press
 * - the sqw signal from RTC
 * - the display's busy spin
 */
void secondsSleep(uint32_t seconds) {
    // convert to microseconds
    uint64_t sleepMicros = seconds * MICROSECONDS_PER______SECOND;

    esp_deep_sleep_disable_rom_logging();  // seems to have no effect
    esp_sleep_disable_wakeup_source(ESP_SLEEP_WAKEUP_ALL);

    wakeup_action_e wakeupType = device.deviceActions[device.actionIndexCur].wakeupType;

    ModuleSignal::prepareSleep();            // this may hold the neopixel power, depending on color debug setting
    ButtonAction::prepareSleep(wakeupType);  // establishes gpio holds for the button pins, ...
    SensorTime::prepareSleep(wakeupType);    // establishes gpio hold for the RTC_SQW pin, ...
    ModuleDisp::prepareSleep(wakeupType);    // adds ext0Wakeup (wait for busy pin high)

    if (wakeupType == WAKEUP_ACTION_BUTN) {
        esp_sleep_enable_ext1_wakeup(device.ext1Bitmask, ESP_EXT1_WAKEUP_ANY_LOW);
    }

    esp_sleep_enable_timer_wakeup(sleepMicros);
    gpio_hold_en((gpio_num_t)I2C_POWER);  // power needs to be help or sensors will not measure

    Wire.end();

    ModuleSignal::setPixelColor(COLOR____OCEAN);
    esp_deep_sleep_start();  // waiting for powerup (up to ~50 seconds) -> deep sleep
}

/**
 * wait with short delays until any of the conditions below become true
 * - the specified seconds have elapsed
 * - isDelayRequired() becomes false
 * - actionNumEntry has changed (some button action may have completed)
 */
void secondsDelay(uint32_t seconds) {

    uint32_t millisEntry = millis();
    uint32_t millisBreak = millisEntry + seconds * MILLISECONDS_PER______SECOND;
    uint16_t actionNumEntry = actionNum;

    wakeup_action_e wakeupType = device.deviceActions[device.actionIndexCur].wakeupType;

    ButtonAction::attachWakeup(wakeupType);  // button interrupts
    ModuleDisp::attachWakeup(wakeupType);    // wait for busy pin
    SensorTime::attachWakeup(wakeupType);    // SQW interrupt

    ModuleSignal::setPixelColor(COLOR_____CYAN);
    while (isDelayRequired() && millis() < millisBreak && actionNumEntry == actionNum) {

        delay(50);

        // the 1 minute measure pin
        if (SensorTime::isInterrupted()) {
            scheduleDeviceActionPowerup();
            break;
        }

        // the display's busy pin
        if (ModuleDisp::isInterrupted()) {
            scheduleDeviceActionDepower();
            break;
        }

        // wifi expiry
        uint32_t secondsdest = ModuleWifi::getSecondstimeExpiry();
        uint32_t secondstime = SensorTime::getSecondstime();
        uint32_t secondswait = secondsdest > secondstime ? secondsdest - secondstime : WAITTIME________________NONE;
        if (secondswait == WAITTIME________________NONE && config.wifi.wifiValPower == WIFI____VAL_P__CUR_Y) {
            ModuleSignal::beep();
            config.wifi.wifiValPower = WIFI____VAL_P__PND_N;  // set flag to pending off
            scheduleDeviceActionSetting();
            break;
        }

        // anything ModuleHttp wants to configure (display aspects, co2 calibration, co2 reset, co2 power mode)
        if (ModuleHttp::requestedReconfiguration != nullptr) {
            ModuleSignal::beep();
            ModuleHttp::requestedReconfiguration(config, values);
            ButtonAction::adapt(config);  // be sure buttons reflect potentially altered configuration
            scheduleDeviceActionSetting();
            ModuleHttp::requestedReconfiguration = nullptr;
            break;
        }
    }

    ButtonAction::detachWakeup(wakeupType);
    ModuleDisp::detachWakeup(wakeupType);
    SensorTime::detachWakeup(wakeupType);
}

device_action_e getActionIndexMax() {
    if (values.nextMeasureIndex >= values.nextDisplayIndex) {
        return DEVICE_ACTION_DEPOWER;  // go all the way up to display/depower
    } else if (values.nextMeasureIndex >= values.nextAutoPubIndex) {
        return DEVICE_ACTION_SETTING;  // run settings, but do not display
    } else if (values.nextMeasureIndex >= values.nextAutoNtpIndex) {
        return DEVICE_ACTION_SETTING;  // run settings, but do not display
    } else {
        return DEVICE_ACTION_READVAL;
    }
}

String getActionName(device_action_e action) {
    if (action == DEVICE_ACTION_POWERUP) {
        return "powerup";
    } else if (action == DEVICE_ACTION_MEASURE) {
        return "measure";
    } else if (action == DEVICE_ACTION_READVAL) {
        return "readval";
    } else if (action == DEVICE_ACTION_SETTING) {
        return "setting";
    } else if (action == DEVICE_ACTION_DISPLAY) {
        return "display";
    } else if (action == DEVICE_ACTION_DEPOWER) {
        return "depower";
    } else {
        return "unknown";
    }
}

void loop() {
    device_action_t action = device.deviceActions[device.actionIndexCur];
    if (SensorTime::getSecondsUntil(action.secondsNext) == WAITTIME________________NONE) {  // action is due
        ModuleSignal::setPixelColor(action.color);
        device.actionIndexCur = Device::getFunctionByAction(action.type)(config, device.actionIndexMax);  // execute the action and see whats coming next
        if (device.actionIndexCur == DEVICE_ACTION_POWERUP) {
            device.actionIndexMax = getActionIndexMax();
            device.deviceActions[DEVICE_ACTION_POWERUP].secondsNext = SensorTime::getSecondstime() + SECONDS_PER_____________HOUR;  // long interval, we want to wake from SQW signal
        } else {
            device.deviceActions[device.actionIndexCur].secondsNext = SensorTime::getSecondstime() + action.secondsWait;
        }
        delay(10);
    }
    uint32_t secondsWait = SensorTime::getSecondsUntil(device.deviceActions[device.actionIndexCur].secondsNext);
    if (secondsWait > WAITTIME________________NONE) {
        if (isDelayRequired()) {
            secondsDelay(secondsWait);
        } else {
            secondsSleep(secondsWait);
        }
    }
}

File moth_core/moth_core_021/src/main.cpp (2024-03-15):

#include "BoxBeep.h"
#include "BoxClock.h"
#include "BoxConn.h"
#include "BoxDisplay.h"
#include "BoxEncr.h"
#include "BoxFiles.h"
#include "BoxMqtt.h"
#include "BoxPack.h"
#include "ButtonHandler.h"
#include "ButtonHandlers.h"
#include "LoopReason.h"
#include "Measurement.h"
#include "Measurements.h"
#include "SensorBme280.h"  // wrapper for bme280 sensor
#include "SensorPmsa003i.h"
#include "SensorScd041.h"  // wrapper for scd41 sensor
#include "driver/rtc_io.h"

typedef enum {
    SENSORS_TRYREAD,  // sensors need to read before measurement can be taken
    SENSORS_GETVALS   // sensors can provide values from measurements previously
                      // taken
} sensors_mode_t;

loop_reason_t loopReason = LOOP_REASON___________UNKNOWN;
loop_reason_t loopAction;

sensors_mode_t sensorsMode = SENSORS_TRYREAD;  // start with SENSORS_TRYREAD (measurement needs to be
                                               // taken)

const int64_t MICROSECONDS_PER_SECOND = 1000000;  // 1 second
const int64_t MILLISECONDS_PER_SECOND = 1000;     // 1 second
const int64_t MEASUREMENT_WAIT_SECONDS_MAX = 1;
const int64_t WAIT_SECONDS_NEVER = 60 * 60 * 24;  // 24 hours, which will effectively never be waited for due
                                                  // to other (shorter) timeouts
const int64_t TRYREAD_SECONDS = 6;

int64_t offsetBeginSeconds = 0;
int64_t lastMemBufferIndex = -2;  // the last mem buffer index that got rendered

bool isAudio;

std::function<void(void)> displayFunc = nullptr;  // [=]()->void{};
// TODO :: define functions for all buttons (maybe attachable to the button
// handlers) this could maybe create the possibility to move the
// handleButtonChangeA, ... methods to the button handlers could there be a
// typedef that holds both action AND display character for that action

/**
 * -- perform tests with various configurations, including invalid ones
 *
 * -- validate (test)
 *    ✓ preventSleep == false
 *    ✓ csvBufferSize == 60
 *    ✓ csv file is written
 *    ✓ file response is working
 *    ✓ mqtt config was successfully read
 *    ✓ encr was successfully read
 *    ✓ timezone works
 *    ✓ time gets adjusted while permanently being online
 *    ✓ time gets adjusted hourly when offline
 *    ✓ mqtt gets published hourly when offline
 */

void setup() {
    Serial.begin(115200);
    Wire.begin();
    delay(2000);

    BoxBeep::begin();
    BoxFiles::begin();
    BoxClock::begin();
    BoxDisplay::begin();  // BoxFiles required to read config
    BoxPack::begin();
    BoxEncr::begin();  // BoxFiles required to read config
    BoxConn::begin();  // BoxFiles and BoxEncr required to read config
    BoxMqtt::begin();  // BoxFiles and BoxEncr required to read config
    Measurements::begin();

    BoxPack::tryRead();  // need to read to have value on splash

    BoxDisplay::renderMothInfo(BoxConn::VNUM);
    BoxDisplay::hibernate(true);  // must be true to maintain Serial

    ButtonHandlers::begin();

    SensorBme280::begin();
    SensorScd041::begin();
    SensorPmsa003i::begin();

    offsetBeginSeconds = BoxClock::getDate().secondstime();
}

int64_t getMeasureNextSeconds() {
    return (Measurements::memBufferIndx + 1) * Measurements::measurementIntervalSeconds + offsetBeginSeconds;
}

int64_t getMeasureWaitSeconds() {
    return getMeasureNextSeconds() - BoxClock::getDate().secondstime();
}

int64_t getDisplayNextSeconds() {
    return (lastMemBufferIndex + BoxDisplay::renderStateSeconds / 60) * Measurements::measurementIntervalSeconds + offsetBeginSeconds;
}

int64_t getDisplayWaitSeconds() {
    return getDisplayNextSeconds() - BoxClock::getDate().secondstime();
}

int64_t getTryReadWaitSeconds() {
    if (sensorsMode == SENSORS_TRYREAD) {
        return getMeasureWaitSeconds() - TRYREAD_SECONDS;  // 5 seconds is the command duration of a
                                                           // single shot measurement
    } else {
        return WAIT_SECONDS_NEVER;
    }
}

int64_t getWarmupWaitSeconds() {
    if (SensorPmsa003i::getMode() == PMS_PAUSE_M) {
        return getMeasureWaitSeconds() - SensorPmsa003i::WARMUP_SECONDS;
    } else if (SensorPmsa003i::getMode() == PMS_PAUSE_D) {
        return getDisplayWaitSeconds() - SensorPmsa003i::WARMUP_SECONDS;
    } else {
        return WAIT_SECONDS_NEVER;
    }
}

void handleButtonChangeA() {
    fallrise_t fallrise11 = ButtonHandlers::A.getFallRise();
    if (fallrise11 == FALL_RISE_FAST) {
        if (ButtonHandlers::A.buttonActionFast.loopReason != LOOP_REASON___________UNKNOWN) {
            loopReason = ButtonHandlers::A.buttonActionFast.loopReason;
        }
    } else if (fallrise11 == FALL_RISE_SLOW) {
        if (ButtonHandlers::A.buttonActionSlow.loopReason != LOOP_REASON___________UNKNOWN) {
            loopReason = ButtonHandlers::A.buttonActionSlow.loopReason;
        }
    }
}
void handleButtonChangeB() {
    fallrise_t fallrise12 = ButtonHandlers::B.getFallRise();
    if (fallrise12 == FALL_RISE_FAST) {
        if (ButtonHandlers::B.buttonActionFast.loopReason != LOOP_REASON___________UNKNOWN) {
            loopReason = ButtonHandlers::B.buttonActionFast.loopReason;
        }
    } else if (fallrise12 == FALL_RISE_SLOW) {
        if (ButtonHandlers::B.buttonActionSlow.loopReason != LOOP_REASON___________UNKNOWN) {
            loopReason = ButtonHandlers::B.buttonActionSlow.loopReason;
        }
    }
}
void handleButtonChangeC() {
    fallrise_t fallrise13 = ButtonHandlers::C.getFallRise();
    if (fallrise13 == FALL_RISE_FAST) {
        if (ButtonHandlers::C.buttonActionFast.loopReason != LOOP_REASON___________UNKNOWN) {
            loopReason = ButtonHandlers::C.buttonActionFast.loopReason;
        }
    } else if (fallrise13 == FALL_RISE_SLOW) {
        if (ButtonHandlers::C.buttonActionSlow.loopReason != LOOP_REASON___________UNKNOWN) {
            loopReason = ButtonHandlers::C.buttonActionSlow.loopReason;
        }
    }
}

bool isRenderStateRequired() {
    return getDisplayWaitSeconds() <= 0 || BoxDisplay::hasSignificantChange();
}
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

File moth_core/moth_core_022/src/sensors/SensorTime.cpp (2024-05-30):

#include "SensorTime.h"

#include <sntp.h>
#include <time.h>

#include "modules/ModuleCard.h"
#include "types/Define.h"

RTC_PCF8523 SensorTime::baseSensor;
bool SensorTime::ntpWait = false;
bool SensorTime::interrupted = false;

/**
 * called once when the device boots
 */
void SensorTime::configure(config_t& config) {
    SensorTime::baseSensor.deconfigureAllTimers();
    SensorTime::baseSensor.enableCountdownTimer(PCF8523_FrequencyMinute, 1);
}

/**
 * called every time the main setup function is called
 */
void SensorTime::begin() {
    SensorTime::baseSensor.begin();

    rtc_gpio_deinit(PIN_RTC_SQW);
    pinMode(PIN_RTC_SQW, INPUT_PULLUP);

    sntp_servermode_dhcp(1);
    sntp_set_time_sync_notification_cb(SensorTime::handleNtpUpdate);
}

/**
 * the rtc sqw pin pulls low once per minute
 */
void SensorTime::prepareSleep(wakeup_action_e wakeupType) {
    if (wakeupType == WAKEUP_ACTION_BUTN) {
        gpio_hold_en(PIN_RTC_SQW);
        rtc_gpio_pullup_en(PIN_RTC_SQW);
        rtc_gpio_pulldown_dis(PIN_RTC_SQW);
    } else {
        gpio_hold_dis(PIN_RTC_SQW);
    }
}

void SensorTime::attachWakeup(wakeup_action_e wakeupType) {
    if (wakeupType == WAKEUP_ACTION_BUTN) {
        attachInterrupt(digitalPinToInterrupt(PIN_RTC_SQW), SensorTime::handleInterrupt, FALLING);
        SensorTime::interrupted = false;
    }
}

void SensorTime::detachWakeup(wakeup_action_e wakeupType) {
    if (wakeupType == WAKEUP_ACTION_BUTN) {
        detachInterrupt(digitalPinToInterrupt(PIN_RTC_SQW));
        SensorTime::interrupted = false;
    }
}

void SensorTime::handleInterrupt() {
    SensorTime::interrupted = true;
}

bool SensorTime::isInterrupted() {
    return SensorTime::interrupted;
}

void SensorTime::setupNtpUpdate(config_t& config) {
    setenv("TZ", config.time.timezone, 1);  //  Now adjust the TZ.  Clock settings are adjusted to show the new local time
    tzset();
    configTzTime(config.time.timezone, "pool.ntp.org", "time.nist.gov");  // will trigger actual ntp update call
    SensorTime::ntpWait = true;
}

/**
 *  Callback function (get's called when time adjusts via NTP)
 */
void SensorTime::handleNtpUpdate(struct timeval* t) {
    struct tm timeinfo;
    getLocalTime(&timeinfo);
    DateTime now(timeinfo.tm_year + 1900, timeinfo.tm_mon + 1, timeinfo.tm_mday, timeinfo.tm_hour, timeinfo.tm_min, timeinfo.tm_sec);
    SensorTime::baseSensor.adjust(now);
    Config::setUtcOffsetSeconds(SECONDS_FROM_1970_TO_2000 + now.secondstime() - t->tv_sec);
    SensorTime::ntpWait = false;
}

bool SensorTime::isNtpWait() {
    return SensorTime::ntpWait;
}

uint32_t SensorTime::getSecondsUntil(uint32_t secondsdest) {
    uint32_t secondstime = SensorTime::getSecondstime();
    return secondsdest > secondstime ? secondsdest - secondstime : WAITTIME________________NONE;
}

uint32_t SensorTime::getSecondstime() {
    return SensorTime::baseSensor.now().secondstime();
}

file32_def_t SensorTime::getFile32Def(uint32_t secondstime, String fileFormat) {
    return SensorTime::getFile32Def(DateTime(SECONDS_FROM_1970_TO_2000 + secondstime), fileFormat);
}

file32_def_t SensorTime::getFile32Def(DateTime date, String fileFormat) {
    char pathBuffer[10];
    sprintf(pathBuffer, "/%04d/%02d", date.year(), date.month());
    char nameBuffer[22];
    sprintf(nameBuffer, "/%04d/%02d/%04d%02d%02d.%s", date.year(), date.month(), date.year(), date.month(), date.day(), fileFormat);
    String name = String(nameBuffer);
    return {String(pathBuffer), name, ModuleCard::existsPath(name)};
}

file32_def_t SensorTime::getFile32DefData(uint32_t secondstime) {
    return SensorTime::getFile32DefData(DateTime(SECONDS_FROM_1970_TO_2000 + secondstime));
}

file32_def_t SensorTime::getFile32DefData(DateTime date) {
    file32_def_t fileDefDap = SensorTime::getFile32Def(date, FILE_FORMAT_DATA_PUBLISHABLE);
    if (ModuleCard::existsPath(fileDefDap.name)) {
        return fileDefDap;
    }
    file32_def_t fileDefDar = SensorTime::getFile32Def(date, FILE_FORMAT_DATA____ARCHIVED);
    if (ModuleCard::existsPath(fileDefDar.name)) {
        return fileDefDar;
    }
    return FILE_DEF_EMPTY;
}

bool SensorTime::isPersistPath(String path) {
    String persistPath = SensorTime::getFile32Def(SensorTime::getSecondstime() - SECONDS_PER_____________HOUR, FILE_FORMAT_DATA_PUBLISHABLE).name;
    return persistPath.indexOf(path) >= 0;
}

String SensorTime::getDateTimeSecondsString(uint32_t secondstime) {
    DateTime date = DateTime(SECONDS_FROM_1970_TO_2000 + secondstime);
    char timeBuffer[32];
    sprintf(timeBuffer, "%04d-%02d-%02dT%02d:%02d:%02d", date.year(), date.month(), date.day(), date.hour(), date.minute(), date.second());
    return timeBuffer;
}

String SensorTime::getDateTimeDisplayString(uint32_t secondstime) {
    DateTime date = DateTime(SECONDS_FROM_1970_TO_2000 + secondstime);
    char timeBuffer[32];
    sprintf(timeBuffer, "%02d.%02d.%04d,%02d:%02d", date.day(), date.month(), date.year(), date.hour(), date.minute());
    return timeBuffer;
}

String SensorTime::getDateTimeLastModString(File32 file) {
    uint16_t pdate;
    uint16_t ptime;
    file.getModifyDateTime(&pdate, &ptime);
    DateTime modifyDate(FS_YEAR(pdate), FS_MONTH(pdate), FS_DAY(pdate), FS_HOUR(ptime), FS_MINUTE(ptime), FS_SECOND(ptime));
    return SensorTime::getDateTimeLastModString(modifyDate.secondstime());
}

String SensorTime::getDateTimeLastModString(uint32_t secondstime) {
    DateTime dateUtc = DateTime(SECONDS_FROM_1970_TO_2000 + secondstime - Config::getUtcOffsetSeconds());
    char timeBuffer[32];
    sprintf(timeBuffer, "%s, %02d %s %04d %02d:%02d:%02d GMT", SensorTime::getNameOfDay(dateUtc), dateUtc.day(), SensorTime::getNameOfMonth(dateUtc), dateUtc.year(), dateUtc.hour(), dateUtc.minute(), dateUtc.second());
    return timeBuffer;
}

String SensorTime::getNameOfDay(DateTime date) {
    uint8_t indexOfDay = date.dayOfTheWeek();
    if (indexOfDay == 0) {
        return "Sun";
    } else if (indexOfDay == 1) {
        return "Mon";
    } else if (indexOfDay == 2) {
        return "Tue";
    } else if (indexOfDay == 3) {
        return "Wed";
    } else if (indexOfDay == 4) {
        return "Thu";
    } else if (indexOfDay == 5) {
        return "Fri";
    } else if (indexOfDay == 6) {
        return "Sat";
    } else {
        return "NA";
    }
}
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

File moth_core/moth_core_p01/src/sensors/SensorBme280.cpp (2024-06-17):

#include "SensorBme280.h"

Adafruit_BME280 SensorBme280::baseSensor;
values_bme_t SensorBme280::values = {0.0f};
bool SensorBme280::hasBegun = false;

void SensorBme280::begin() {
    SensorBme280::baseSensor.begin();
    SensorBme280::hasBegun = true;
}

bool SensorBme280::configure(config_t& config) {

    Serial.println("SensorBme280::configure");

    // whats currently set
    float temperatureOffsetV = SensorBme280::getTemperatureOffset();
    // whats about to be set
    float temperatureOffsetC = -config.sbme.temperatureOffset;

    Serial.printf("temperatureOffsetV: %u, temperatureOffsetC: %u\n", temperatureOffsetV, temperatureOffsetC);

    // apply, only if there is a real change
    bool temperatureApplied = false;
    if (abs(temperatureOffsetV - temperatureOffsetC) > 0.01) {
        Serial.printf("!!! applying temperature offset, %f, %f !!!\n", temperatureOffsetV, temperatureOffsetC);
        SensorBme280::baseSensor.setTemperatureCompensation(temperatureOffsetC);
        temperatureApplied = true;
    } else {
        Serial.printf("no temperature offset application needed, %f, %f\n", temperatureOffsetV, temperatureOffsetC);
    }

    return temperatureApplied;
}

bool SensorBme280::measure() {
    return true;
}

values_bme_t SensorBme280::readval() {
    SensorBme280::values = {SensorBme280::baseSensor.readTemperature(), SensorBme280::baseSensor.readHumidity(), SensorBme280::baseSensor.readPressure() / 100.0f};
    return SensorBme280::values;
}

float SensorBme280::getTemperatureOffset() {
    return SensorBme280::baseSensor.getTemperatureCompensation();
}

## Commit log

2023-05-08 first stls
    [housing_lower.stl, housing_upper.stl]
2023-05-08 polygon orders
    [housing_lower.stl, housing_upper.stl]
2023-05-08 secondary stls
    [buttons.stl, mountplugs.stl]
2023-05-08 polygon order
    [buttons.stl]
2023-05-08 supports and some readme
    [supports.stl]
2023-05-08 start assembly
2023-05-09 continue assembly instructions
2023-05-09 assembly images
2023-05-09 device assembly
2023-05-11 changes to publish, readme
    [housing_lower_s.stl]
2023-05-12 sketchup drawings
    [buttons.skp, housing_lower.skp, housing_upper.skp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]
2023-05-17 added rtc for precise timing
    [housing_upper.skp, housing_upper.stl, supports2.skp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]
2023-05-17 update mds to show rtc
    [supports2.skp]
2023-05-30 bugfix for device crashing on temperature offset set too early
    [moth_core_020.ino]
2023-06-01 cache-control, config parsing, ...
    [housing_upper.skp, housing_upper_b.stl]
2023-06-02 upper housing with raft
    [housing_upper.skp, housing_upper_b.stl]
2024-01-24 with PMS option
    [boostbuzz.skp, boostbuzz.stl, housing_lower_pms.skp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]
2024-01-26 redesign measure-display cycle
    [buttons.skp, buttons.stl]
2024-02-02 add altitude, refine display
    [button1.stl, button1_tpu.stl, buttons.skp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]
2024-02-03 extends char range in font, refine display
    [buttons.skp, buttons.stl]
2024-02-03 buttons, battery display
    [button1.stl]
2024-02-03 small refinements for pms display
    [button1_tpu.stl, buttons.skp, buttons_tpu.stl]
2024-02-04 fix battery bar indicator length
    [SensorPmsa003i.cpp, moth_core_020.ino]
2024-02-11 low-pass filter to compensate for singoe-shot data being noisier than periodic measurement
2024-02-15 redesign button actions
2024-02-27 co2 reference value, calibration refinement
2024-03-15 low power version, trying to reach 2 months battery life
2024-03-17 work on low power version
2024-04-07 change low pass filter
2024-04-12 low pass filter on pressure
2024-04-13 mqtt handling, low pass filtering
2024-04-14 battery value fix, altitude compensation fix, wifi fix
    [SensorBme280.cpp, main.cpp]
2024-04-14 fix chart display range
    [main.cpp]
2024-04-15 fix gaps in chart
    [main.cpp]
2024-04-21 prepare for better calibration
2024-04-22 more robust calibration
2024-04-23 test low power periodic
2024-05-13 better caching, ui improvements, ui error handling
    [main.cpp]
2024-05-15 work around mqtt memory leak
    [main.cpp]
2024-05-18 fix wifi stuck after disconnect, documentation
    [SensorTime.cpp, main.cpp]
2024-08-24 readme changes
    [housing_upper.skp]
